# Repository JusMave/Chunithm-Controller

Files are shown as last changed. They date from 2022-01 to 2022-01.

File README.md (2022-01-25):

# Chunithm-Controller
This is a customed controller for SAGA's arcade game "Chunithm".

Game Official Link: https://chunithm.sega.com/

My Controller Demo Video: https://www.bilibili.com/video/BV13k4y1k7Bm

### Introduction
  Chunithm is a classical rhythm game with two types of inputs. 
  Users need to touch the screen and raise their hands at the right time to pass the game. 
  The official machine uses a 32-channel touch screen and 8 pairs of infrared detectors to track users' actions.

### Hardware
  My controller also implemented a capacitive touch screen and 8 pairs of infrared detectors to perform the same function.
  The main control chip is ATmega32U4, a powerful and popular chip for individual embedded development.
  It was connected to four capacitance sensor chips. Each of them can accept 4 channels' signals.
  
  In order to save the production cost and make manufacturing more manageable, I also designed PCBs and outer shells. 
  The CAD files are included in "PCB" and "CAD Blueprints"
  
### Software
  This project utilizes the I/O control library provided by Arduino and an open-source program to process serial communication between the control board and game.
  
### Details
  The detailed information is included in "Report.pdf".

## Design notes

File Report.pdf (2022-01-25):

### MACAU UNIVERSITY OF SCIENCE AND TECHNOLOGY

### Faculty of Information Technology

### Thesis for Degree of Bachelor of Science

### Title: “MaveCon” Customizable Universal Arcade Controller

Student Name | : CHEN HANDONG
Student No. | : 1609853Z-I011-0050
Supervisor | : Dai Hong Ning

### May, 2020

# 澳門科技大學

## 資訊科技學院

## 理學學士學位畢業論文

## 論文題目: “MaveCon”客制化泛用型街機控制器

姓 名 | : 陳漢棟
學 號 | : 1609853Z-I011-0050

## 指導老師 : 戴弘寧

2020 年 5 月

I

## Abstract

The golden age of arcade video games has already ended but there still are a

couple of players spend their times and money in game centers to enjoy the fun which

consoles can’t give them. However, because of the high price of arcade cabinet and low

level of population of this kind of games not every game center will buy the latest or the

most high-quality arcade games. Therefore, not everyone in the world have the chance

to play the game they want. Besides, even somebody is lucky enough. They will still

suffer from long travel distance, expensive gaming cost, long time for waiting in line

and terrible maintenance of arcade cabinet.

In order to solve these problems and help more people be able to enjoy this

fascinating but hard-core game category, we present MAVECON, a customizable

universal arcade controller which can let people play any arcade games in their home.

Because almost every arcade game has their own unique input devices especially for

Japanese rhythm games, the controller divide input sensors set and main board into two

parts. These two parts can use JST PH2.0 connectors to connect each other. Therefore,

users can easily change their sensors to fit various arcade games and maintain the

controller to keep its good performance.

At present, we have completed two games’s sensors set. They are Chunithm [2]

and Taiko set. These two games both are well-known rhythm arcade games in Japan and

have a large player base in the world. Chunithm sensors set includes a PMMA

controller shell, 6 pairs Active Infrared Sensors, 32 capacitive touch sensors and 96

TM1812 RGB programable LEDs. Taiko sensors set includes a dedicated wooden shell

and four shock sensors. What’s more, with long time testing, we can be sure to say that

our controller can give almost the same game experience just like real arcade cabinet.

Keywords: home controller; arcade games; universal; customizable

II

摘要

### 雖然街機遊戲的黃金時代已經結束了，但是如今依然有一部分玩家每天在

### 遊戲廳內遊玩街機遊戲來獲得主機遊戲所給予不了的快樂。然而因為街機框體的

### 高價和玩家人數的稀少，並不是所有遊戲廳都會購入最新或者品質最好的街機遊

### 戲。因此並不是所有人都能有機會玩到自己想玩的遊戲。即便遊戲廳有對應的街

### 機，玩家依然要面臨大量的通勤時間，高昂的遊玩價格，極長的排隊等待時間以

### 及街機框體糟糕的維護等嚴重影響遊戲體驗的問題。

### 為了解決這些問題，我們提出了 MAVECON 一款客制化泛用型街機控制

### 器，它可以讓玩家在家中玩到任何想玩的街機遊戲。我們將控制器分為輸入感測

### 器和主控板兩個部分，來應對幾乎每一款街機遊戲都有他們自己獨特的輸入裝置

### 和對應的輸入方式的問題。他們之間可以使用 JST PH2.0 標準插頭連接。玩家可

### 以輕鬆的更換感測器套組來適應不同遊戲的需求並維護設備保持較好的性能。

### 目前我們完成 Chunithm 以及太鼓達人的感測器套組。他們都是在日本十

### 分有名的街機音遊，即便是在如今的環境下在全球範圍內都依然擁有龐大的玩家

### 基數。Chunithm 套組中包含了一個控制器框體，6 對紅外對射感測器，32 個電

### 容觸摸按鍵， 96 顆 TM1812 RGB 可程式設計 LED。太鼓套組包含一套對應框

### 體以及 4 顆震動感測器。經過長時間的測試，我們已經確定該控制器可以給予玩

### 家與真實街機框體幾乎一致的遊戲體驗。

## 關鍵詞﹕遊戲控制器 ﹔ 街機遊戲 ﹔泛用型﹔客制化

III

## Table of Contents

Abstract | I
摘要 | II
Table of Contents | III
List of Figures | VI
List of Tables | VII

IV

V

VI

## List of Figures

VII

## List of Tables

Chapter 1 Introduction

## Chapter 1 Introduction

## 1.1 Background and motivation

Arcade games [1] are one of the oldest and most special game categories across

the history of video games. They are known by their dedicated and highly immersion

game control approaches, superior difficulty and unbelievable complex game

mechanisms which means arcade games cannot be passed without several years

practice. These features made arcade games become the most popular game category

between the late 1970s and the mid-1980s and this period is defined the golden age of

arcade video games.[1] However, with time going by, these features also become the

biggest blocks for attracting new players to this game category. Because of the superior

difficulty and complex game mechanism, people usually need to play it a couple of

years to be a good player which can be costly for both time and money. What’s more,

arcade game devices are extremely expensive and difficult to transport. Therefore, there

are few game centers have the latest and most high-quality arcade games.

Unfortunately, game centers are the only place for more than 99% people to play arcade

games. Hence, the number of arcade game players are going down year by year.

However, in the Japanese gaming industry, arcades have remained popular

through to the present day.[1] There are still many game companies developing new

arcade machines and games. They are still trying to bring some creative features to

improve gameplay. As of 2009, out of Japan's US$20 billion gaming market, US$6

billion of that amount is generated from arcades, which represent the largest sector of

the Japanese video game market, followed by home console games and mobile games at

US$3.5 billion and US$2 billion, respectively.[4] Hence, there are still a couple of

arcade players and people who want to be arcade player in the world. To better help

these people enjoy arcade games, we need to know what make this kind of game is so

hard for players to play.

Generally, problems for people to play arcade games can be divided into two

types. One kind of problems are about cost of playing arcade games including the time

spending on traveling and waiting, the money spending in starting each round. Another

kind of problems are about the rarity of arcade cabinets which means people are hard to

Chapter 1 Introduction

find the arcade game which they want to play. For example, there are total 420 game

centers and 1293 arcade rhythm game machines in China.[5] Most of them are in first-

tier cities. Hence, only few people in China have the chance to play the latest arcade

rhythm games.

In order to solve these two kinds of problems and encourage people to play arcade

games, we developed a fully customizable arcade game home controller which we

called MaveCon. It can be connected to PC, PS4, Nintendo Switch and any other

platforms. It can be used to simulate any arcade games including fighting games,

rhythm games, shooting games and even simulation games in arcade platform. To

achieve these goals, we divide the controller into two parts. One is sensor set which

including all the sensors which you need to simulate the input of arcade cabinet and a

strong shell to fix all the sensors to ensure all the sensors can work properly when users

are playing. Another one is the main control board which are used to control all the

sensors and convert input signals from sensors to output signals which can be

recognized by target platform. At present, there are some different types of arcade game

home controllers in the market. However, because of the unique input approach of each

arcade game. Most controllers can only be used to play one game. What’s more, these

controllers usually are very expensive and cannot be customized. Therefore, those

controllers cannot fulfill everyone’s needs.

All in all, the main goal of us is developing a controller which can give everybody

a chance to play those interesting but rare arcade games without cost lots of money. In

other words, we want to design and implement a controller with low price, high

performance and high productivity. The original design of the controller is for arcade

rhythm games. There is no doubt that the controller can be used in any arcade games.

However, currently we have only finished Chunithm and Taiko sensors set and we

spend most of our effort on Chunithm sensors set. Therefore, we will use Chunithm set

as the sensors set example in this thesis.

## 1.2 Contributions

We present a functional action detecting system including a budget but powerful

self-capacitance touch pad and several high accuracy hands’ position tracking sensors.

Chapter 1 Introduction

We present a cross platform sensor data converting system including a main

board with modular and customizable input interfaces, a high-performance sensors

signals processing approach, HID device simulation function and cross platform feature.

## 1.3 Thesis organization

Chapter 2, we introduce the architecture of MAVECON.

Chapter 3, the details of hardware development in this chapter.

Chapter 4, we describe the implementation of our controller’s software.

Chapter 5, testing and evaluation will be discussed in this chapter.

Chapter 6 concludes the thesis.

Chapter 2 Architecture

## Chapter 2 Architecture

In this chapter, we will illustrate the architecture of MAVECON, which can give

a better understanding of the controller.

## 2.1 Overview

MAVECON consists of three parts. They are sensors set, main board and the code

burned inside the chip. The detailed structure of each part as shown in figure 2-1. Each

part has its unique and irreplaceable functions which will be illustrated in next sections.

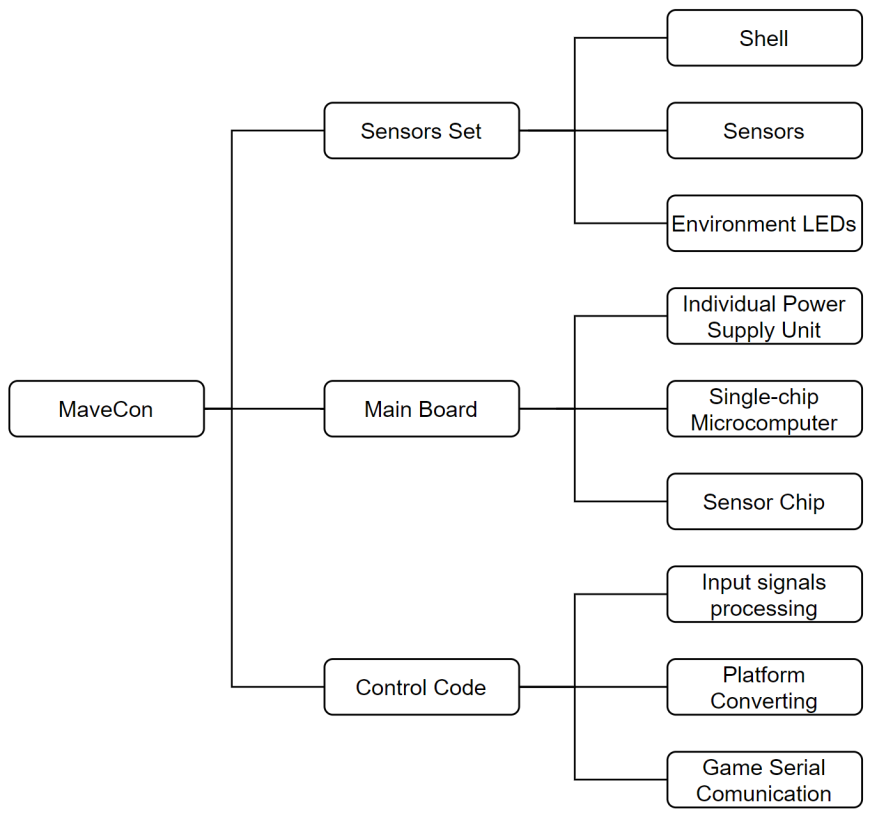
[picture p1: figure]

Figure 2.1 Controller Overview

## 2.2 Sensors Set

Sensors set has three parts including outer shell, sensors and environment LEDs

which is the most significant part for controller to be able to simulate various

completely different arcade games. Users can play different games by changing their

sensors set. All the sets will be budget and easy for users to use. Currently, we have

Chapter 2 Architecture

designed and implemented Chunithm sensors set. We can produce more sets and

improve their performance in the future.

2.2.1 Shell

Shell is used to fix all the sensors and ensure they can work properly when user is

playing. Arcade games are not like those games in consoles or PC. Players are using

individual input devices like controller, keyboard and mouse to give commands and

signals to play the game. Arcade games combine the input devices, screen and any other

devices together in a shell which is called cabinet. What’s more, because of the playing

place of arcade games and hard game difficulty, the cabinet usually cannot get high-

quality maintenance and will be hit hard by players to release their angry and regret.

Hence, almost all the arcade cabinet will be protected very will using industry level

impact resistance materials. The situation is similar for home arcade controller. Because

of the arcade game mechanism especially for rhythm games, players have to hit sensors

very hard to keep their sense of rhythm the same as the game to get a high score.

Therefore, the controller should use strong shell to fix all the sensors and protect them.

Generally, we will use PMMA¹
and 304 stainless steel which both are good

material for making the shell. PMMA is a kind of material with good impact strength

and the most important thing is its low price. For our Chunithm sensors set, we use

PMMA to make the entire shell base and other individual shell parts.

2.2.2 Sensors

Sensors is the most important part of sensors set. They are used to simulate the

same kind of input signals as the arcade games. For example, the main input devices of

Chunithm are one touch screen with 32 touch areas and 6 pairs of air sensors. Hence, in

order to simulate these two kinds of input signals, we use 32 capacitive touch sensors to

input touch, hold and slide signals and 6 pairs Active Infrared Sensors to give air

signals. In order to make all the sensors work in a terrible environment and meet our

1 PMMA: Poly (methyl methacrylate), https://en.wikipedia.org/wiki/Poly(methyl_methacrylate).

Chapter 2 Architecture

original intention of developing such a controller, sensors should be highly reliable and

budget. Hence, we will only choose the most common sensors to make our sensors set.

2.2.3 Environment LEDs

Almost all the arcade video games have complex lighting system which can be

used to show the feedback of user input signals or help games improve the gameplay.

For the controller, environment LEDs have the same function just like arcade games. To

achieve this goal, we choose RGB LEDs with IC chip which can be controlled by address like WS2812B and TM1812²
. Hence, these LEDs can show complex light

effect or even do the same like real arcade games. Most arcade games use serial

communication to control LEDs. What’s more, we have already programed a simple

serial communication port to using arcade games original light system control logical.

Therefore, with correct led settings the controller can have the same light effect just like

real arcade games’ cabinet.

## 2.3 Main Board

The main board of our controller is consisted by single-chip microcomputer,

sensor chip and individual power supply unit. The major function of it is handling input

signals from sensors and output these signals to the arcade games working on different

platforms and provide strong power to support various devices in the controller. To

make the controller easy for users to use, we use JST PH2.0 [16] standard connectors to

connect main board and sensors.

2.3.1 Single-chip Microcomputer

Single-chip microcomputer is the major part in the main board. All the logical

control codes are burned in it including input signals handling, platform converting and

LEDs serial communication. To develop such a hardware-based controller, using single-

chip microcomputer is the best option. Because with the help of suitable single-chip

microcomputer, developers can use high level program languages and take benefit from

2 WS2812B and TM1812 both are an Intelligent control LED integrated light source which can be controlled

by IC chip and output RGB lights. WS2812B’s light direction is vertical to PCB board and TM1812’s light direction

is parallel to the PCB board.

Chapter 2 Architecture

the community. At present, there are countless suitable single-chip microcomputer in

the market. Different microchips have different pros and cons. In this thesis, we use

Arduino pro micro to be our single-chip microcomputer. Because Arduino pro micro

has the best performance and smallest volume among all the supported Arduino compatible boards of keyboard HID library. Sparkfun pro micro uses ATmega32U4³

chip which has powerful performance for making a home gaming controller. What’s

more, pro micro is the smallest Arduino boards among all the products of Arduino.

Hence, the main control board can be small but powerful to reduce the need of setting

space and keep users’ great game experience. Besides, Atmega32U4 is one of the most

common chips in embedded development. Therefore, we can use countless useful third-

party libraries to reduce the cost of our development and improve the performance of

our controller.

2.3.2 Sensor Chip

Sensor chips are necessary part for handling complex sensors like capacitive

touch sensors. Because these sensors do not produce simple digital signals, developers

have to use a complex algorithm to calculate the output value from the sensors and

convert them into simple digital signals. To reduce the effort of making such a

complicated algorithm and its hardware circuit, we use dedicated sensor chips to

complete the job. We use MPR121 to be our sensor chip which are design for capacitive

touch sensors, but it also can handle those sensors which can produce digital signals by

themselves like microswitches. What’s more, multiple MPR121 chips can be called by

their addresses. Hence, we can use multiple sensor chips to manage different groups of

sensors. Because of that, we can greatly increase the range of arcade games which can

be simulated by our controller and reduce the difficulty of maintenance. Besides,

MPR121 has a complex but fully customizable debounce algorithm, a simple static

3 ATmega32U4 is a low-power Microchip 8-bit AVR RISC-based microcontroller featuring 32KB self-

programming flash program memory, 2.5KB SRAM, 1KB EEPROM, USB 2.0 full-speed/low speed device, 12-

channel 10-bit A/D-converter, and JTAG interface for on-chip-debug. The device achieves up to 16 MIPS throughput

at 16 MHz, 2.7 - 5.5 Volt operation.

Chapter 2 Architecture

threshold setting and a dynamic baseline system which can improve the performance of

capacitive touch sensors and make our controller be more customizable.

2.3.3 Individual Power Supply Unit

The function of individual power supply unit is providing enough power to

support all the devices in the controller. The original USB port can only provide 800ma

power which is enough for the microcomputer and sensor chips, but it’s not enough for

LEDs and other high cost devices. Without enough power the reliability of each part in

controller will be greatly reduced. Some sensors and chips may shut down and

microcomputer will also have some running problems. Hence, we use an individual

power supply unit to support the costliest devices in the system. The whole Chunithm

sensors set has 96 LEDs. Each of them needs 60ma power. Hence, if all the LEDs

working full loaded the total power input should be more than 5.76A. Fortunately, full

loaded situation is very rare. Therefore, we use a 5A/24V DC power unit which can

output a little bit less power than the full loaded situation to support the controller. It

can fulfill our needs and make main board power supply traces be smaller to remain

more spaces for logical traces.

## 2.4 Control Code

Control code is burned in the main single-chip microcomputer. The main function

for control code is receiving input signals from sensors and output specific signals to

communicate with different platform using serial or USB communication protocol.

2.4.1 Input signals processing

Most sensors will provide simple digital signals, some other sensors need

algorithms to convert their output value into digital code. All of these signals will be

handled by input signals handler. Handler will use signals to do communication with

arcade games and users can use controller to play the game with the same gameplay as

real arcade cabinet. To improve the performance of sensors, we implemented an

effective debounce algorithm. The technical details will be presented in software

chapter.

Chapter 2 Architecture

2.4.2 Platform Converting

There are a couple of arcade games released console or PC versions. That means

some players may not only want to play arcade games running in PC simulators, but

also want to play those console versions. Hence, we implemented a platform converting

feature. Currently, it can support PS4 and Nintendo Switch. By changing the HID

document, Atmega32U4 can simulate different kinds of input devices like keyboard,

mouse and gaming controller. Currently, only PC and Nintendo Switch can be

simulated by Arduino HID library. For PS4 and other platforms’ simulation, we use

GIMX [6], a well-known free software that allows to use a computer as a hub for

gaming devices. By using our Taiko sensors set, we can play

2.4.3 Game Serial Communication

Most of the arcade games use serial port and serial communication to control

sensors and other I/O devices. If we can use the original serial port to transfer I/O

signals, the input latency will be greatly reduced. Hence, for some games which have

been decrypted and known their serial communication structure, we will use their serial

port to transfer signals especially environment LEDs.

Chapter 3 Development of Hardware

## Chapter 3 Development of Hardware

In this chapter, we will illustrate the technical details of hardware implementation

of our controller and Chunithm sensors set. To improve the performance and reduce the

difficulty of future maintenance, we use modularized structure and development

method. The basic running routine for hardware as shown in Figure 3-1.

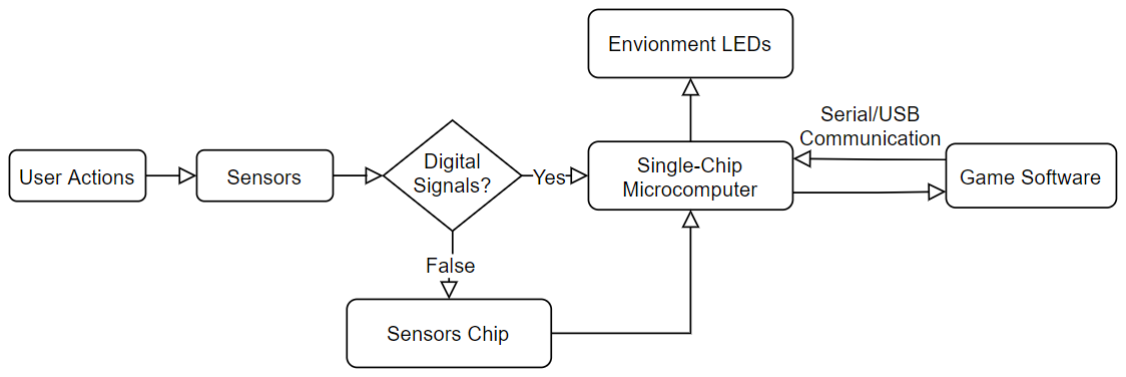
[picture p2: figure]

Figure 3.1 Data Flow of the System

## 3.1 User actions detecting by Sensors

To provider users the same gameplay as the real arcade games, designing a

suitable approach for users to input commands by doing the same actions as real arcade

machine is essential. For Chunithm sensors set, we designed an approach to track users’

input commands just like Chunithm arcade machine.

3.1.1 Game Mechanism

In order to give better understanding for why we designed such an approach, it is

necessary to know the game basic mechanisms.

Chunithm is a modern drop-style rhythm game in arcade platform. This kind of

games use a scrolling "note highway" to display what notes are to be played, along with

a score and a performance meter. Generally, players need to input click, hold to play the

game. If players can keep inputting right commands at right timing, they can get score.

Otherwise, they cannot get score and will lose their HP. The game will fail when the HP

is 0. There are totally four kinds of actions in Chunithm. They are touch, hold, slide and

Chapter 3 Development of Hardware

air. Players need to touch and release the touch screen immediately to generate touch

signal. Keeping touching the screen will give hold signals. If players keep touching the

screen and slide their hands from one area to another area, it will provide slide signals.

Finally, air signals will be generated when players hover in the air and between air

sensors.

3.1.2 Selection of Sensors

To generate touch, hold and slide signals and try to simulate the gameplay as

better as possible. We decide to use touch screen to complete the job. Arcade machine

uses acoustic wave type touch screen which is an extremely rare and expensive

approach. To keep our controller budget for everyone can get, we decide to use other

more common approaches to implement touch screen. There are two common touch

screen implementation methods in the world. First is capacitive touch screen, second is

resistive touch screen. The former one has the advantages of lower prices and more

simple structure which can be made even without professional industry machines.

Besides, it is more suitable to make such a big touch screen without precise position

detecting. Hence, we decide to use capacitive touch screen to be our main input sensors.

To output air signals, we need to detect the position of users’ hands. Only output

air signals, when users’ hands hovering at a specific height. There are two effective

approaches. First, we can use a camera and a motion detecting algorithm to track the

position of hands. Second, using sensors to directly detect whether there are hands

going through. First approach needs much bigger space than the second one. Because

we need enough distance to make camera work properly. Besides, if we use first

approach, the whole system will be much more unreliable. The devices settings will be

insignificantly difficult to calibrate. Hence, we decide to use Active Infrared Sensors to

finish the job. Those sensors have excellent performance for tracking objects’ position.

They can output digital signals with an extraordinary low latency which can be a major

benefit for a rhythm gaming controller.

Chapter 3 Development of Hardware

3.1.3 Implementation of Sensors

### 3.1.3.1 Capacitive Touch Screen

Capacitive touch screen uses capacitive sensing technology, based on capacitive

coupling, that can detect and measure anything that is conductive or has a dielectric

different from air. Its technical principles as shown in Figure 3-2

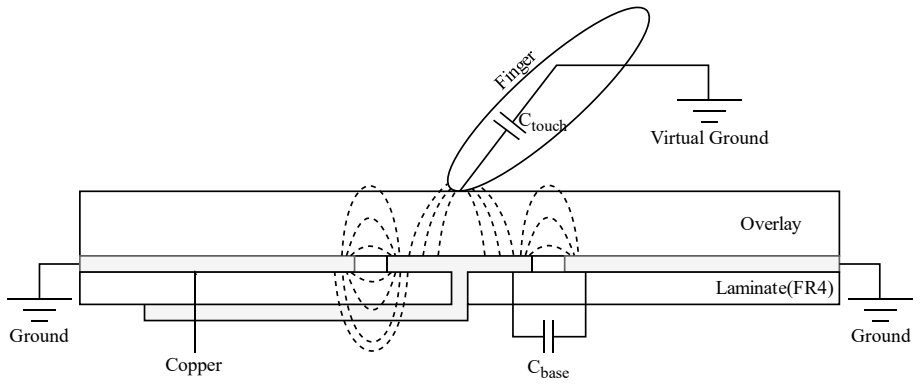
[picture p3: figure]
Cbase; Ground; irtual Ground; Ctouch; Laminate FR4; Overlay; Copper

Figure 3.2 Capacitive Sensor Overview

A capacitor is a device that stores electrical energy in an electric field. It is a

passive electronic component with two terminals. For capacitive touch screen, copper

and finger are the two terminals and overlay are dielectric medium. Hence, we can get a

capacitor and detecting the touch action by tracking the change of electrical energy in

this capacitor.

According to the basic theory of parallel-plate capacitor, we can get the formula.

The capacitance is defined as C = Q/V. Hence, here is the final formula for

capacitive sensors.

Therefore, in a capacitor the highest capacitance is achieved with a high dielectric

constant material, large plate area, and small separation between the plates. What’s

Chapter 3 Development of Hardware

more, the highest capacitance means the sensitive of the sensor. Higher sensitive can

give clearer and stronger signals. Therefore, in order to get as higher sensitive as we

can, we increased the size of copper terminal, thinner and higher permittivity dielectric

overlay. There are a couple of approaches to implement a functional capacitive touch

sensor. We can use ITO, metal, PCB board and many other materials to complete it. In

order to reduce the difficulty of manufacture and assembly. We decide to use PCB to

make our capacitive touch sensor. Besides, environment LEDs will also be soldered on

the touch sensor board. To find the best sensor PCB, we designed and tested three versions of PCB design. The first version PCB design⁴
of capacitive touch sensor as

shown in Figure 3-3.

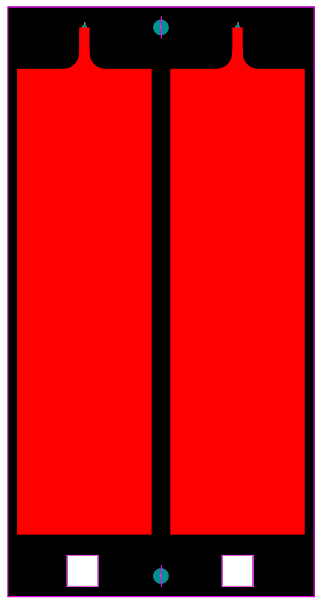
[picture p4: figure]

Figure 3.3 Capacitive Sensor Board V1.0

4 We use Altium Designer 2020 and AutoCAD 2020 to draw all the parts. All the color and meaning of line

and icons will follow their default settings. All the PCB board in this thesis follow the standard:

⚫ | 1.6mm.FR2
⚫ | Solder mask over bare copper
⚫ | 1oz copper
⚫ | Solder mask on both layers
⚫ | Supplied as singles

Chapter 3 Development of Hardware

We will use 8 sensor boards to form touch screen. It has totally 16 touch areas

and 16 WS2812B environment LEDs. The overlay uses PMMA material with frosted

surface which have high permittivity dielectric and can help lights have a better effect.

However, the V1.0 design has three problems.

⚫ | The sensors cannot detect touching if users touch the area between two
| copper areas.
⚫ | Because of the uneven surface of frosted PMMA material, there is air
| between copper and overlay. Hence, the sensitivity of sensors is influenced. It
| will be a little bit lower than normal PMMA surface.
⚫ | The game software needs 32 touch areas, but by using V1.0 design we can
| only support 16 touch areas. Therefore, we designed another version to fix
| these problems.

Hence, we designed another version of our sensor board and overlay. The second

version of capacitive touch sensor as shown in Figure 3-4.

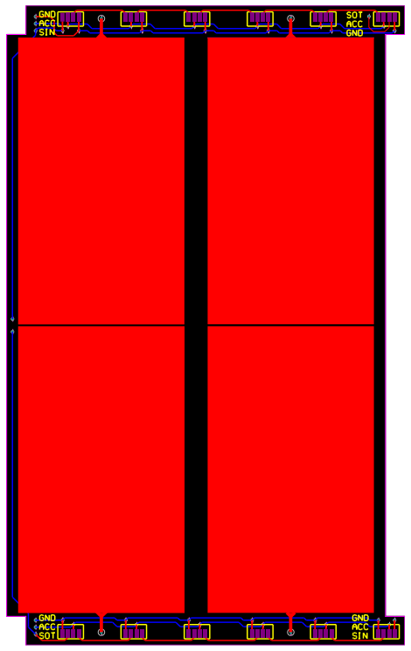
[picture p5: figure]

Figure 3.4 Capacitive Sensor Board V2.0

Chapter 3 Development of Hardware

In the sensor board V2.0, we divide one touch area into two areas to support 32

touch areas like arcade machine. Besides, we added environment LEDs’ soldering area

to combine the LEDs and sensors board together to improve the performance of lighting

system and simplify assemble process. The material of overlay is also changed. We

select laser dotted light guide plate (LGP) which are made by PMMA material with

smooth surface. Hence, there is less air between copper and overlay than frosted surface

PMMA which can improve the sensitivity of sensors. The technical details about laser

dotted LGP will be illustrated in next sub section.

After testing the second version sensor board, we conclude all the benefits from

each version design and present our final version sensor board as shown in Figure 3-5.

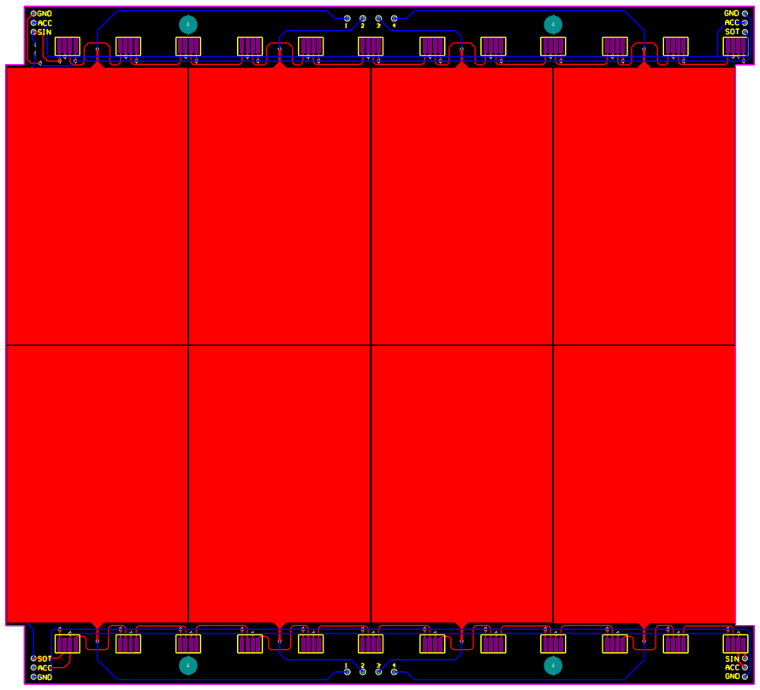
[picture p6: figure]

Figure 3.5 Capacitive Sensor Board Final Version

### 3.1.3.2 Active Infrared Sensors

Active infrared sensors usually consist of a pair of electronic sensors that

measures infrared (IR) light. One is the transmitting end and another is the receiving

end. Transmitting end will continuously beam IR light. If the IR light is blocked by

Chapter 3 Development of Hardware

some objects, the receiving end cannot receive the IR light. Then, it will generate digital

signals and send them through the signal port. Because of the physical features of IR

light and the special structure of the devices, IR light can travel long distance with high

strength.

There are two types of Active infrared sensors. Break beam sensors and

reflectance sensors.

Break beam sensors have emitter and receiver placed face to face that the IR

emitted by the emitter falls directly in to the receiver. During the operation, IR beam is

emitted continuously towards the receiver. The flow of IR can be interrupted by placing

an object between the emitter and receiver. If the IR is transmitted but altered then

receiver generates output based on the change in radiation. Similarly, if the radiation is

completely blocked the receiver can detect it and provide the desired output. For

example: let’s consider a Break beam sensor and a conveyer belt as shown in figure 3-6.

When an opaque object interrupts the IR flow the receiver doesn’t receive any signal

thus the conveyer belt stops.[8]

Figure 3.6 Break Beam Sensor

Reflectance sensors use reflective property of IR. The emitter emits an IR beam

which is reflected by the object. The reflected IR is the detected by the receiver. The

object causes change in the property of the reflected IR or the amount of IR received by

the receiver varies. The degree of change is dependent on the reflectance of the object.

Thus, detecting the change in amount of received IR helps in figuring out the properties

of object such as surface geography and reflectance.[8]

Chapter 3 Development of Hardware

Figure 3.7 Reflectance Sensor

Because of the game mechanism, break beam sensor is more suitable for our

controller. Besides, it can be easier to calibrate and generate clear digital signals. Hence,

we use a shell structure to fix six pairs of break beam sensors to track users’ action.

Because game software only supports six signal inputs, so we only use six pairs of

sensors.

In order to improve their performance in different working environment

especially working with other light source which may interfere the function of receiving

end, we select active IR sensors using modulated light signals. That means the emitter

will emit light in a special frequency and the receiving end will only generate signals

when it cannot receive the light in that frequency.

Figure 3.8 Modulated Active IR Sensors

However, when we use multiple active IR sensors together, there are another

problem. The receiver may receiver light signals from other IR emitters, which means it

will not generator signals even there is an object between it and its original IR emitter.

Chapter 3 Development of Hardware

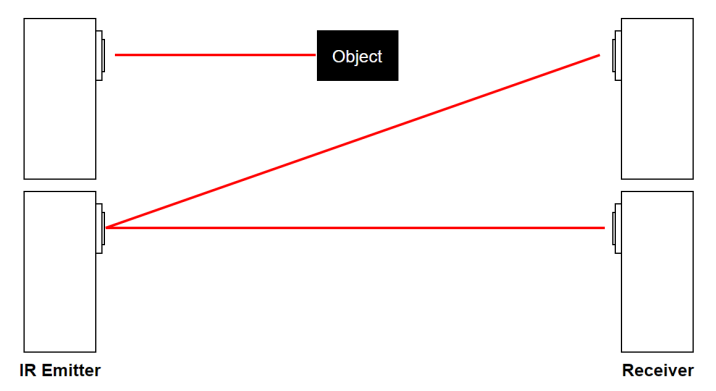
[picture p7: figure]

Figure 3.9 Receiving Light from Other Emitter

So, we designed a cover panel to block light signals from other IR emitters. This

panel can also greatly improve the sensor performance in bright environment.

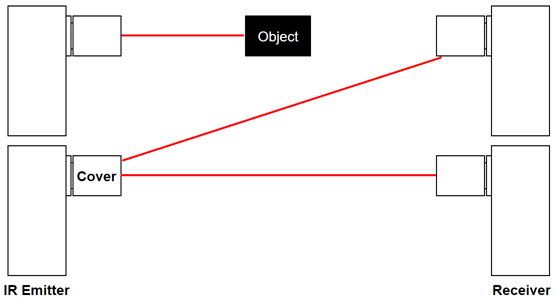
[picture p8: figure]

Figure 3.10 Extra Cover Panel

## 3.2 Design and Implementation of Shell and LEDs

3.2.1 Outer Shell

In order to fix all the sensors and give more customization possibility, we spend a

lot of effort to design a suitable shell for our controller. Because of the demand of

different sensors, outer shell has two parts to install different types of sensor which are

shell base, top panel and air sensor holder.

### 3.2.1.1 Shell Base

Shell base is the most significant part for keeping the controller stable when users

are playing. To increase its strength, we first tried 304 stainless steel, which is a

common metal material in industry products. The design is shown in Figure 3-11.

Chapter 3 Development of Hardware

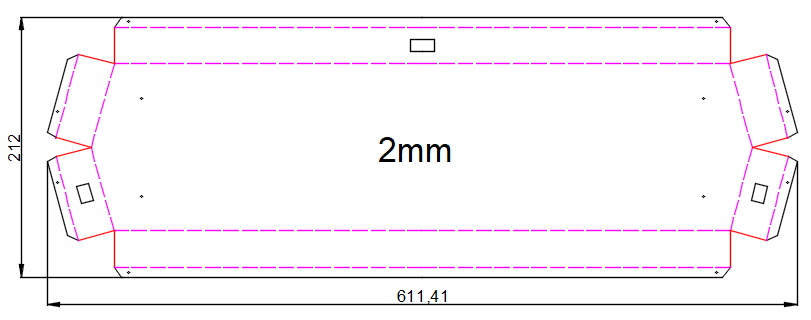
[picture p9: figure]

Figure 3.11 Steel Shell Base V1.0⁵

However, the error of steel material bending and welding process is too serious to

pass our assembly test. Therefore, we decide to use PMMA material to build outer shell

and try to design each part as simpler as possible to reduce process difficulty. The

design is shown in Figure 3-12.

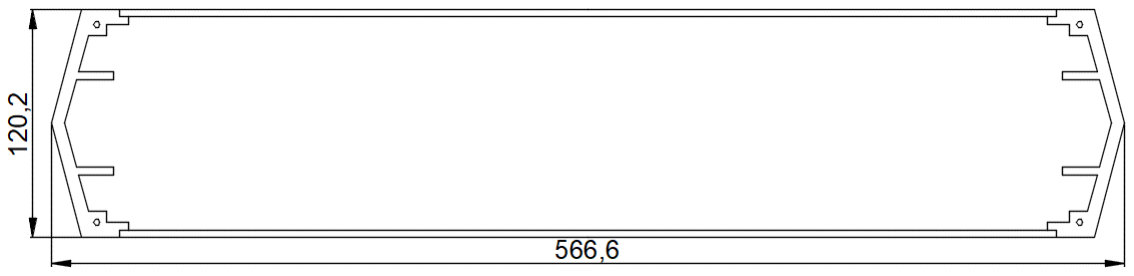
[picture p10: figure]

Figure 3.12 PMMA Shell Base V2.0

### 3.2.1.2 Top panel

Top panel are used to fix all the touch sensors and connect to air sensor holder.

Besides, it should be removable. Because the controller should be easy for users to

5 Followings are the meanings of all the icon and color in CAD Drawings:

Black Line: Cutting line

Red Line: Welding line

Pink Line: Bending line

The unit of all the number: mm

Chapter 3 Development of Hardware

maintenance. Hence, each part in the controller having possibility to be broken should

be replaceable without special tools. The design is shown om Figure 3-13.

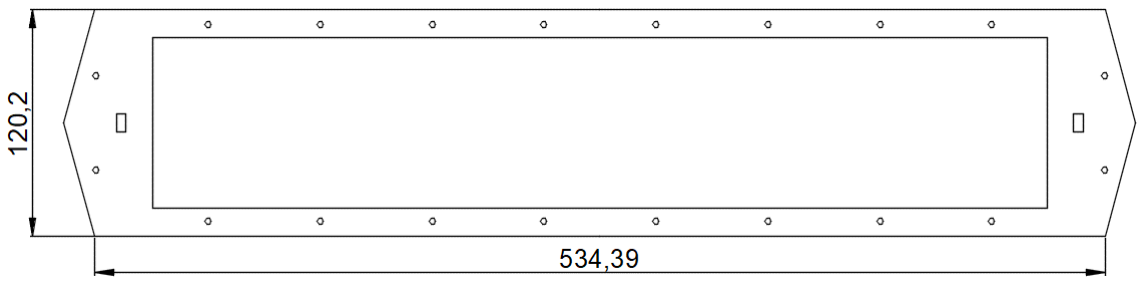
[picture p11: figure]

Figure 3.13 PMMA Top Panel

### 3.2.1.3 Air Sensor Holder

air sensor holder is the part have the most components. It is used to install active

IR sensors. Because the detecting area of IR sensors are not big enough. Hence, we

create customizable sensor base to make the controller can fit anyone’s demand. Users

can choose to stand and play the controller like playing arcade machines or sit on the

chair and play games like playing console games. Because of the basic technical

principle of active IR sensors, they need a dark environment to perform their function.

Hence, we added extra cover panels which can be installed on the holder to keep sensors

working in a dark environment. Whether to install these panels and install how many

panels depend on users. Our design can support cover panels up to 4. All the

components are shown in Figure 3-14.

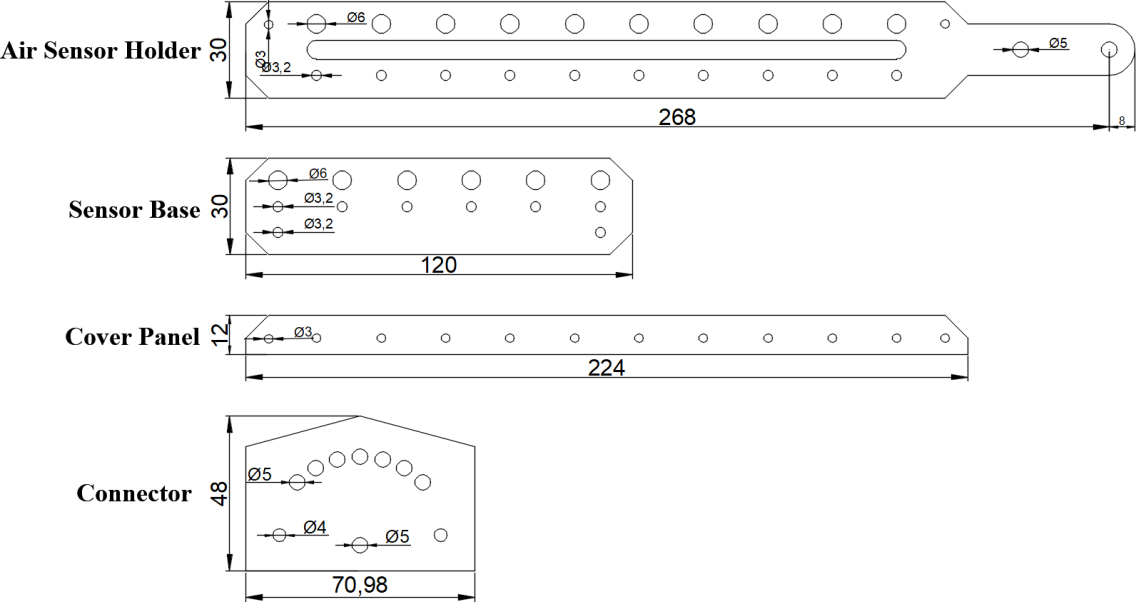
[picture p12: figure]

Figure 3.14 The CAD Drawing of Air Sensor Holder V1.0

Chapter 3 Development of Hardware

3.2.2 Environment LED

Environment light system is made by two parts. The LED and LGP. The first

version of LGP frame design as shown in Figure 3-15.

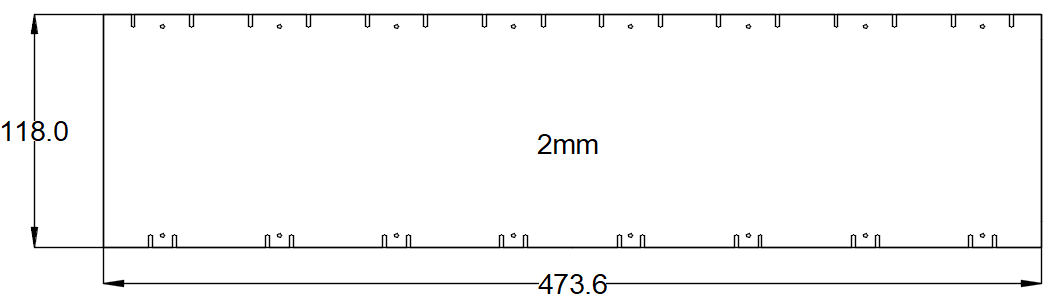
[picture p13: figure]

Figure 3.15 LGP Frame V1.0 CAD Drawing

We use this version of LGP frame with WS2812B LED [9] as shown in Figure 3-

16.

Figure 3.16 WS2812B

WS2812B is an intelligent control LED light source that the control circuit and

RGB chip are integrated in a package of 5050 components.[9] It is a very popular and

useful RGB LED in industry scale. Thousands of programable lighting systems are

made by WS2812B. Hence, in the first version design, we also tried this kind of LED.

However, common WS2812B using the 5050 packages. Hence, they can only

emit light to vertical direction. After physical test, the effect of this approach is not

good. They can only light up a small area of LGP. Besides, the first version of LGP

frame design also has problems about different LEDs’ light may interfering each other

which means the light effect are not clear enough for players to recognize their input

commands by watching the light color. Therefore, in order to construct a high-quality

lighting system. We redesigned back light unit structure. The new structure as shown in

Figure 3-17.

Chapter 3 Development of Hardware

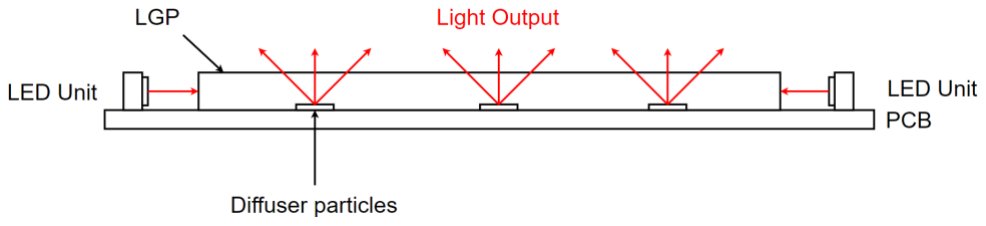
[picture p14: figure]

Figure 3.17 Back Light Unit (Backlit unit) Structure

This back light unit structure needs a LED can emit light in parallel direction and

a suitable LGP frame design. Firstly, we select a TM1812 [10] RGB LED. It has similar

appearance and functions to WS2812B, but it uses a different package to emit parallel

light. Secondly, we designed the second version of LGP frame which can use reflective

coating to prevent light interfering. The design is shown in Figure 3-18.

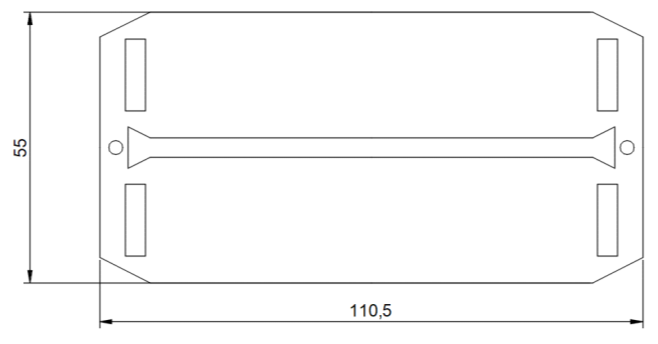
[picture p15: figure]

Figure 3.18 LGP Frame V2.0 CAD Drawing

Besides, we also need to select a suitable type of light guide plate (LGP) to be the

LGP frame material. Generally, there are two types of LGP in industry scale. They are

laser LGP and silk print LGP. The differences are shown in table 3-1.

Type of LGP | Reflector Method | Dimensions | Reflecting Material | Anti-UV | Light Transmittance Rate | Error | Quality Guarantee | Application Environment
Laser Dotted | Laser Concaved Point | 3D | No Addition Material | Yes | 93% | 0.1mm | 10 years | Indoor and outdoor
Sile Print | Raised Point | 2D | Print Ink | No | 70% | 1mm | 2 years | Indoor only

Table 3.1 Comparison between the Laser LGP and Silk print LGP

Chapter 3 Development of Hardware

Hence, we can find that laser dotted LGP has much more advantages than silk

print LGP. What’s more, the material of laser dotted LGP is Mitsubishi optical acrylic

(PMMA) which has many excellent features including high light transmittance,

uniformity reach to 90%, no yellowing, long life span (at least 10 years), no addition

chemical substance and high permittivity dielectric. Because of these advantages, we

select it to be the material to make our LGP frame. [11]

## 3.3 Implementation of Main Board

In this section, we will illustrate the approach to implement main board. It is

consisted by four sensor chips and one single-chip microcomputer. Main board is used

to process all the input signals and output processed signals to game platform.

3.3.1 Sensor chips

Because not all the sensors can generate simple digital signals by themselves.

Some sensors can only output analog signals or other types of value. Hence, we need

use special algorithm to handle these output values and convert them into direct and

effect value to track users’ action. In order to reduce the cost of development and

enhance the reliability of our system, we use Adafruit MPR121 12-channel capacitive

touch sensor breakout board’s compatible board to finish the job. MPR121 can handle

up to 12 individual touch pads. The MPR121 has support for only I2C, which can be

implemented with nearly any microcontroller. Developers can select one of 4 addresses

with the ADDR pin, for a total of 48 capacitive touch pads on one I2C 2-wire bus.

Using this chip is a lot easier than doing the capacitive sensing with analog inputs: it

handles all the filtering for users and can be configured for more/less sensitivity. [12]

Because of these features, we can use MPR121 to implement a touch screen

including at most 48 touch pads which can be fit most arcade games’ demand. Besides,

the board can process not only analog signals, but also digital signals. Hence, we can

connect sensors which can generate digital signals like microswitches to the board. It

can greatly enhance the generality of our controller. Users also can find some creative

approaches to implement their own controller by using our main board. The MPR121

board is shown in Figure 3-19

Chapter 3 Development of Hardware

Figure 3.19 MPR121- Breakout Compatible Board

3.3.2 Single-chip Microcomputer

There are thousands of various single-chip microcomputers in the market. To give

a better understanding about why we choose Sparkfun pro micro, we will present our

reasons from multiple aspects.

### 3.3.2.1 Requirements of Microcomputer

Before illustrate the reasons, we should know what kind of microcomputer is

suitable for our project.

⚫ | High Performance and High Reliability
⚫ | Big and Active Community
⚫ | Easy for Software and Hardware Development
⚫ | Small Size and Low Price

Firstly, because it is responsible for most computation. If the microcomputer

shutting down or crashed when users are playing, the controller will stop work. Hence,

high performance and high reliability of the microcomputer are very important.

Secondly, because of differences between various microcomputers’ bottom

hardware structure, the implementation of software which have the same functions will

be different. If the microcomputer can be supported well by the community, the

development cost will be greatly decreased. For example, the HID simulation function

is necessary for our project. Popular chips have countless useful and high-quality HID

simulation libraries. By using them, our controller can have a much better performance

Chapter 3 Development of Hardware

and less development time than using most not popular chips. Therefore, we try to find

a most common used microcomputer and have the biggest and most active community.

Thirdly, microcomputer is relative to both software and hardware development.

More exactly, we should use different programing language to develop our software and

design PCB with different complexity to integrate sensor chips and microcomputer

depending on the microcomputer. Hence, we should find a microcomputer which can be

easy for software and hardware development.

Finally, the size of microcomputer should be small with low price. Because our

controller should be able for everyone to play at home. Hence, each component should

be as small as possible except outer shell which should have the same size like arcade

input devices with low price to reduce the cost.

### 3.3.2.2 Selection of Microcomputer

It was estimated in mid-2011 that over 300,000 official Arduinos had been

commercially produced,[5] and in 2013 that 700,000 official boards were in users'

hands. There is no doubt that Arduino products have one of the biggest and most active

community in the world. Hence, we decide to find a suitable product from Arduino

microcomputer product line. The usage of Arduino Board as shown in Figure 3-20.

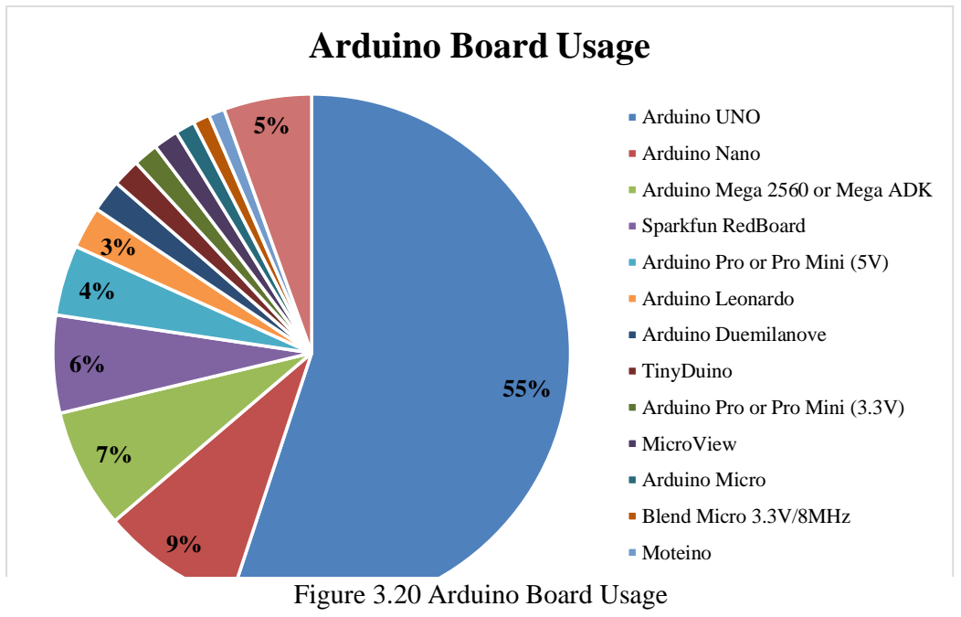
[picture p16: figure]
Arduino Board Usage; Arduino UNO; Arduino Nano; Arduino Mega 2560 or Mega ADK; Sparkfun RedBoard; Arduino Pro or Pro Mini (5V); Arduino Leonardo; Arduino Duemilanove; TinyDuino; Arduino Pro or Pro Mini (3.3V); MicroView; Arduino Micro; Blend Micro 3.3V/8MHz; Moteino Other Figure 3.20 Arduino Board Usage

Chapter 3 Development of Hardware

Arduino UNO definitely is the most common used Arduino Board, but it is too big for

our project. Atmega328P is the most popular processor as shown in Figure 3-21.

However, Atmega32U4 can use the same code running by Atmega328P and it has USB

transceiver inside the chip which can do away with bulky external USB interface.

Hence, we finally decide to use sparkfun pro micro which has a small size, low price

and high performance for us to make a controller. The software development can be

supported by Arduino IDE and many useful third-party libraries.

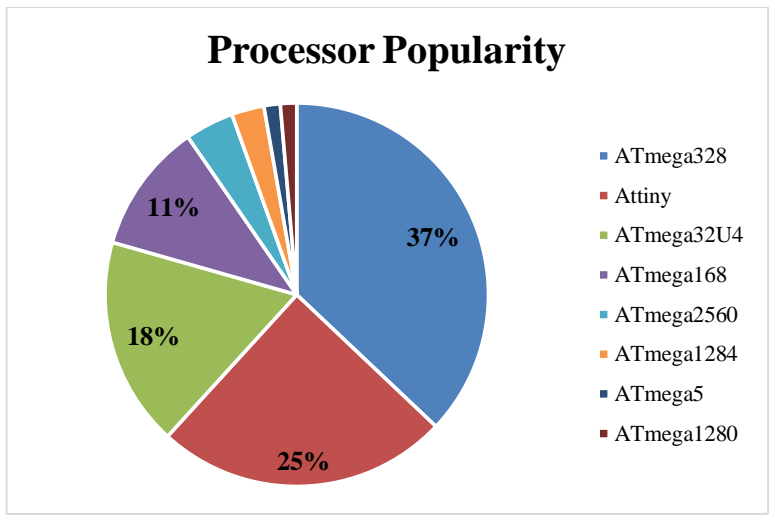
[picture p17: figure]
Processor Popularity; ATmega328; Attiny; ATmega32U4; ATmega168; ATmega2560; ATmega1284; ATmega5; ATmega1280

Figure 3.21 Processor Popularity

Sparkfun Pro Micro has 3.3V and 5V versions. One can run at 3.3V/8MHz.

Another can run at 5V/16MHz. To get higher performance, we select 5V/16MHz

version.

Pro micro can only output 500ma current which is not enough for all the

environment LEDs. Hence, we added an individual power supply unit.

3.3.3 PCB of Main Board

Because of the requirement of our controller, every component in the project

should be fixed well and can be replaced or installed without special tools. Hence, we

designed a PCB to integrate sensor chips, microcomputer and power supply unit. We

Chapter 3 Development of Hardware

also use JST PH2.0 standard connector to reduce the difficulty of connecting sensors to

main board. The design is shown in Figure 3-23.

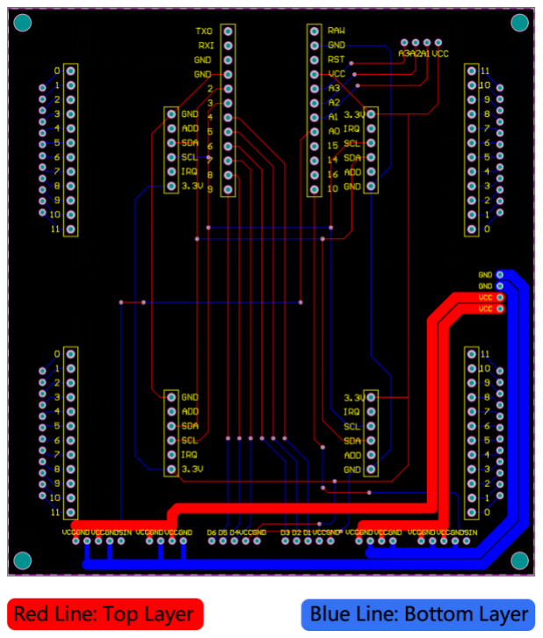
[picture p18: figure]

Figure 3.22 PCB design of Main Board

Environment LEDs need about 5A current. Because of the current heating effect,

we need wider power traces to keep its temperature in the safe zone. The effect is shown

in Figure 3-24. Generally, 5A current needs about 6mm wide trace. However, the space

is not enough for 6mm power traces and ground traces. Therefore, we use 4mm traces

and divide environment LEDs into two group to balance the load of power trace. We try

to design the main board within 10cm * 10cm size is because most PCB producers will

give the lowest price for boards within that size. If the board is larger than 10cm *

10cm, the price will be at least twice the original price. It will greatly increase the

development cost and the difficulty of production.

Chapter 3 Development of Hardware

Figure 3.23 Trace current capacity on 1oz PCB

Besides, we added an extra encoder connector for further development. It can be

used to change current supported game of the controller so that users need not to

recompile or reburn the code to fit different games.

3.3.4 Individual Power Supply Unit

There are various individual power supply units (PSU)in the market. Generally, A

power supply unit is used to convert mains AC to low-voltage regulated DC power for

the internal components of a computer. The function is a little bit different for our

controller. It has an individual AC-DC converter which is used to convert 220V AC

power to 24V DC power. Then, it uses DC power to support LEDs and other

components in the board. The technical details about our PSU is shown in Table

Operating Voltage | DC 9V-36V
Output Voltage | 5.2V/5A/25W
Output Ability | 9~24V input: 5.2V/6A/30W output
24~32V input: 5.2V/5A/25W output 32~36V input: 5.2V/3.5A/18W output Table 3.2 Technical Parameters of Controller’s PSU

Chapter 4 Development of Software

## Chapter 4 Development of Software

In this chapter, we will discuss the implementation of our code. To give a better

understanding about how the controller work from software aspect. The code structure

is shown in Figure 4-1.

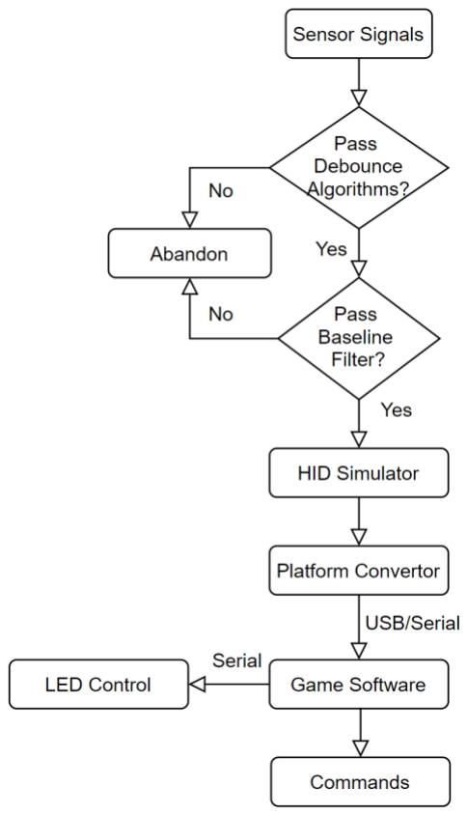
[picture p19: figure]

Figure 4.1 Data Flow Diagram

## 4.1 Debounce Algorithm and Baseline System

In this section, we will illustrate the implementation of debounce algorithm and

MPR121 Baseline system.

4.1.1 Debounce Algorithm

Contact bounce (also called chatter) is a common problem with mechanical

switches and relays, which arises as the result of electrical contact resistance (ECR)

phenomena at interfaces. Switch and relay contacts are usually made of springy metals.

Chapter 4 Development of Software

When the contacts strike together, their momentum and elasticity act together to cause

them to bounce apart one or more times before making steady contact. The result is a

rapidly pulsed electric current instead of a clean transition from zero to full current. The

effect is usually unimportant in power circuits, but causes problems in some analogue

and logic circuits that respond fast enough to misinterpret the on‑off pulses as a data

stream.[17] In the design of micro-contacts controlling surface structure (surface

roughness) and minimizing the formation of passivated layers on metallic surfaces are

instrumental in inhibiting chatter.

The effects of contact bounce can be eliminated by use of mercury-wetted

contacts, but these are now infrequently used because of the hazards of mercury.

Alternatively, contact circuit voltages can be low-pass filtered to reduce or eliminate

multiple pulses from appearing. In digital systems, multiple samples of the contact state

can be taken at a low rate and examined for a steady sequence, so that contacts can

settle before the contact level is considered reliable and acted upon. Bounce in SPDT

switch contacts signals can be filtered out using a SR flip-flop (latch) or Schmitt trigger.

All of these methods are referred to as 'debouncing'. [18]

The bounce problem will also happen in analog signal sensors like capacitive

sensors, shock sensors which are using in our sensors set. Because of lacking in test

circuit design and development budget, we choose software to do debounce. The

implementation of original debounce algorithm in MPR121 chip is obtaining multiple

samples and testing them with the baseline value. If any of these samples fail to pass the

test, these signals will be abandoned. However, this algorithm can cause serious input

latency. Hence, we implemented a debounce algorithm with rate-limiting and throttling

the frequency of sensor signals’ receiving. The effect of algorithm is shown in Figure 4-

2.

Chapter 4 Development of Software

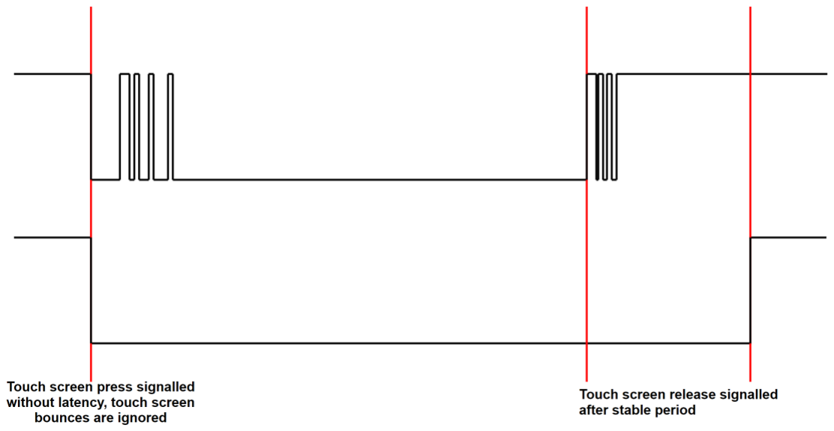
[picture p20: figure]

Figure 4.2 The Effect of Debounce Algorithm

From the figure we can find that the current level will be unstable when user press

and release the switch. Therefore, we limited the input frequency and set a fixed press duration. Currently, the world record for most mouse clicks in 1 second is 16CPS⁶
. [19]

Hence, we limited the input frequency to 20CPS. In other words, the controller will not

generate 2 signals in 50ms. The limitation even is a little bit higher than the record.

Therefore, it will not cause problems with missing input data for most users. By using

these measures, the bounces when user press and release the switch will be ignored.

Users can generate clear input signals and the game will have stable and correct actions.

4.1.2 Baseline System

Besides having bounce problem, touch sensors also have noise problem. In signal

processing, noise is a general term for unwanted (and, in general, unknown)

modifications that a signal may suffer during capture, storage, transmission, processing,

or conversion. [20] Hence, we also need an algorithm to filter them. The purpose of the

baseline filter is to “filter out touches” resulting in a system that is similar to a long-

term average but also takes into account that one specific signature. A touch must have

different properties than noise and environmental change with respect to the filter

response. This is accomplished through four register types that operate under different

6 CPS: Click per second

Chapter 4 Development of Software

conditions. These are Max Half Delta (MHD), Noise Half Delta (NHD), Noise Count

Limit (NCL) and Filter Delay Limit (FDL). [21] We can change the value of these

registers to customize the baseline filter and get clear touch signals. The data flow is

shown in Figure 4-3.

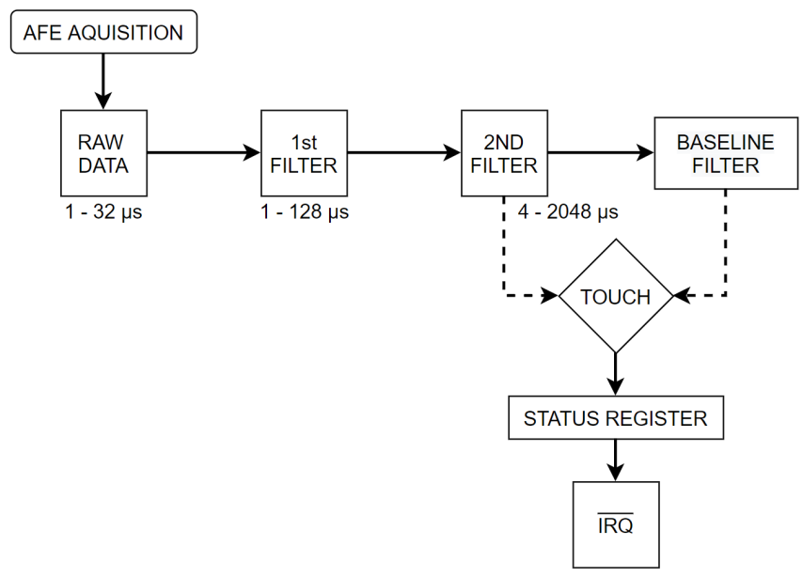
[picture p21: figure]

Figure 4.3 Data Flow in the MPR121

## 4.2 HID Device Simulation

4.2.1 Purpose of HID Device Simulation

In order to output signals which can be accepted by the game software, we need

to convert our controller into specific devices with correct driver which can be

identified by the target platform. For example, Windows 10 identify devices by their

HID drivers. We can use keyboard with keyboard drivers to input commands, but we

cannot use it with mouse drivers. Because the actions of some switches are not defined

in the driver. Hence, the system may cannot identify it or cannot receive right input

commands.

4.2.2 Selection of HID Device

There are various HID devices like gamepad, mouse, midi keyboard and other

devices in the world. To provide an unlimited software environment for the controller,

we consider the most suitable HID device is NKRO keyboard. NKRO keyboard has a

Chapter 4 Development of Software

significant feature that normal keyboards do not have. It has n-key rollover feature. This

means that each key is scanned completely independently by the keyboard hardware, so

that each keypress is correctly detected regardless of how many other keys are being

pressed or held down at the time. The drivers for PC system are also different. With

NKRO keyboard driver, the number of input commands which system can accept at the

same time is unlimited. Normal keyboards only have 6-key rollover which means they

can only input at most 6 keys once. It is not a big problem for daily used keyboard.

However, if the device is a game device, there is no doubt that it will greatly influence

the game experience especially for fighting game and rhythm game which are the most

popular genres in arcade games. Our controller has 32 touch sensors and 6 active IR

sensors. Hence, user can input at most 38 commands once which is much greater than

normal keyboard input limitation.

4.2.3 Implementation of HID Device Simulation

Arduino company has implemented a simple keyboard library [22]. However, it is

a normal keyboard library which means it can only input 6 keys once. Therefore, we

need to find another way to complete this function. Then, we find a third-party library

from GitHub. Its name is Arduino HID Project [23] which provide a simply approach

for developers to implement a NKRO keyboard.

The HID library provides two approaches to implement NKRO Keyboard

simulation. The first approach is similar with Arduino official keyboard library. We

need to use press() and release() functions to output a key command. The second

approach use add() and send() functions to output a series of added key commands. In

order to give clear game commands and improve users’ game experience, we use press

and release() to complete the basic logic of sending keyboard commands.

## 4.3 Platform Convertor

Most of arcade games can be played in PC platform by using various simulators

and similar fan-fiction works. These games can be played directly by the controller’s

default settings. However, there are a couple of arcade games having official console

games in PS4, XBOX and Nintendo Switch. In order to expand controller’s function

Chapter 4 Development of Software

and reduce the cost for new players to enjoy arcade games, we implemented a platform

convertor to make the controller still functional in console platforms.

Generally, we use third-party project GIMX [6] to implement our platform

convertor. GIMX is a free software that allows to use a computer as a hub for gaming

devices. It works on Windows and GNU/Linux platforms. It is compatible with

PlayStation and Xbox gaming consoles. The structure of GIMX is shown in Figure 4-4.

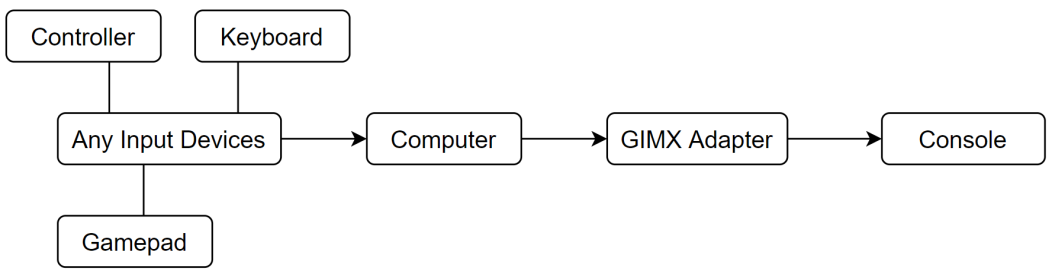
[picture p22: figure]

Figure 4.4 GIMX Structure

GIMX adapter is a USB adapter which can be made by AVR development board

like Sparkfun pro micro which is used in our main board. At present, GIMX project can

support PS4, PS3, Xbox One and Xbox 360. The controller will be converted to specific

console controller with good performance.

For Nintendo Switch, we use HID simulation function. The reason why we do

not use it to complete other platforms conversion is PlayStation and Xbox having an

extra identification process to check whether the connected device is the controller with

identification chip inside. However, for Nintendo Switch, it does not have such

procedure. Hence, we can simply change the HID information and simulate our

controller to be a Nintendo Switch official controller.

Unfortunately, because of the implementation approach of our controller, PC

mode cannot coexist with NS mode. In other words, we need to recompile the code to

change the mode of the controller to support different platform. It can be improved by

adding extra switch. For PlayStation and Xbox, they can coexist with PC mode.

Because GIMX is working in PC environment.

Chapter 4 Development of Software

## 4.4 Serial Communication and LED Control

Serial communication is the process of sending data one bit at a time,

sequentially, over a communication channel or computer bus. For most arcade

machines, they use serial communication to finish most of their data transmissions.

Hence, we implemented our LED control code by receiving values from the game

software. Sensors signals also can be transmitted by serial communication, but because

of the mechanism of serial communication, it has serious problem with data missing.

Sensor signals are the most significant part in our project. It should be stable with low

latency. Hence, if we want to use that we need to finish an extra structure for solving

this problem, it will spend much more time with little improvement for our controller.

Therefore, we decide to use USB communication for sensor signals and use Serial

communication for LED control.

There are totally 96 LEDs in our controller. They can be divided into 32 groups.

16 groups with 64 LEDs are touch area LEDs. 15 groups with 30 LEDs are the area

between two touch area. Finally, 1 group with 2 LEDs are redundant. By leaving an

extra redundant group can reduce the difficulty of production. We have left a

customizable value for users to change the data serial port. The controller will change

LEDs’ RGB value by receiving the data from that serial port.

Chapter 5 Testing

## Chapter 5 Testing

## 5.1 Main Board

In this section we will test the function of our main board. Generally, main board

has two functions. They are receiving signals and transmit these signals to game

platform. We tested the connection between four MPR121 chips and pro micro.

MPR121 chip has a begin() function to check the connection status. The result is shown

in Figure 5-1.

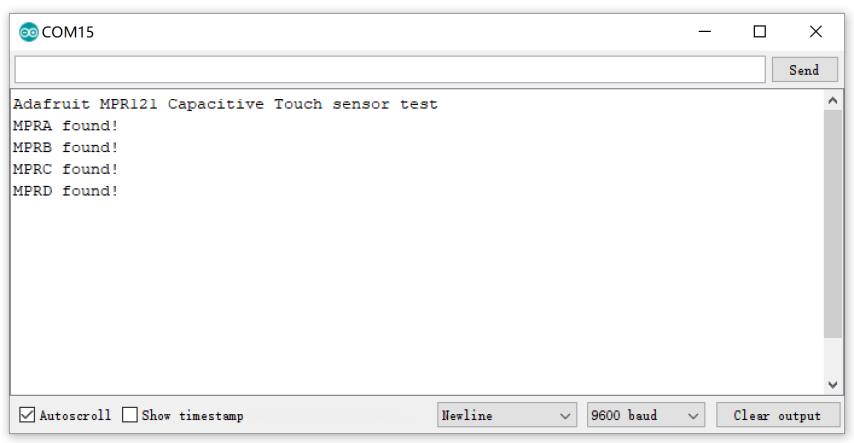
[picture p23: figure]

Figure 5.1 MPR121 Testing Result

Besides, power supply unit is functional, it can support all of our devices. The

finished main board is shown in Figure 5-2.

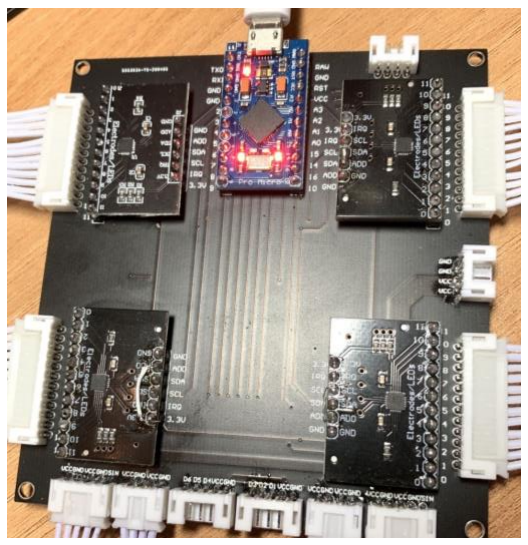
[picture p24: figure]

Figure 5.2 Complete Main Board

Chapter 5 Testing

## 5.2 Sensors Set

In this section, we test the function of all the sensors in our sensors set. There are

totally 8 actions divided by action types, speed and intensity. The result is shown in

Table 5-1. According to the result, we can find that the touch screen can receive heavy

click, hold, fast slide well and active IR sensors can always track users’ action clearly.

However, because of the theory of self-capacitance sensors, light click and low speed

slide have serious signal missing problems when we touch the sensor with LGP.

Fortunately, the problem can be simply fixed by removing LGP.

Actions Result | Click (Light) | Click (Heavy) | Hold | Slide (Fast) | Slide (Normal) | Slide (Slow) | Air (Flick) | Air (Hover)
Received | 21 | 48 | 49 | 41 | 32 | 17 | 50 | 47
Missed | 29 | 2 | 1 | 12 | 18 | 33 | 0 | 3
Input Number | 50 | 50 | 50 | 50 | 50 | 50 | 50 | 50

Table 5.1 The Result of Sensor Testing with LGP

Actions Result | Click (Light) | Click (Heavy) | Hold | Slide (Fast) | Slide (Normal) | Slide (Slow) | Air (Flick) | Air (Hover)
Received | 49 | 48 | 49 | 47 | 48 | 43 | 50 | 48
Missed | 1 | 2 | 1 | 3 | 2 | 7 | 0 | 2
Input Number | 50 | 50 | 50 | 50 | 50 | 50 | 50 | 50

Table 5.2 The Result of Sensor Testing without LGP

Chapter 6 Conclusion

## Chapter 6 Conclusion

## 6.1 Conclusion

We have presented an approach to build a customizable universal arcade

controller. The controller can support most of arcade games in the market and some of

the console games which have similar input mechanism like arcade games. All the

components in the controller are budget and easy for user to maintenance. We designed

sensors set and main board two individual structures which can let users play

completely different games by using the same controller. Besides, they are protected

well by the shell structure. Hence, the controller can work properly in poor environment

without regular maintenance. Therefore, it will be a good device for new players who

want to play arcade games.

## 6.2 Future work

We use self-capacitance structure to make our touch screen, but its sensitivity is a

little bit too low to track every small action made by users. Using mutual- capacitance

structure may have better performance. Besides, a functional hardware debounce

structure should be added to the PCB. The debounce algorithm cannot handle all the

situation. Some noises still will cause unexpected input signals.

The PCB design of touch sensors should add extra JST connectors to further

reduce the difficulty of production and maintenance. The main board should a little bit

larger to give more space for power and ground traces.

Reference & Bibliography

## Reference & Bibliography

[1] Wikipedia, “Arcade game”, https://en.wikipedia.org/wiki/Arcade_game
[2] Wikipedia, “Chunithm”, https://en.wikipedia.org/wiki/Chunithm
[3] H. Lee, H. Jeong and J. Han, "Arcade video game platform built upon multiple

sensors," 2008 IEEE International Conference on Multisensor Fusion and

Integration for Intelligent Systems, Seoul, 2008, pp. 111-113.

[4] Sambe, Yukiharu (2009). "Japan's Arcade Games and Their Technology". Lecture

Notes in Computer Science. Entertainment Computing– ICEC 2009.

[5] Bemanicn, “Chinese rhythm games map”, https://map.bemanicn.com/.
[6] GIMX, “GIMX – GIMX adapts your gaming devices!”, https://blog.gimx.fr/
[7] E. S. Koptev and D. V. Ryabchinskiy, "Decrease of the Error of Measurement of

Self-Capacitance with Least Squares Method," 2018 XIV International Scientific-

Technical Conference on Actual Problems of Electronics Instrument Engineering

(APEIE), Novosibirsk, 2018, pp. 252-254.

[8] Sensor Technology, “Infrared sensors”,

https://wiki.metropolia.fi/display/sensor/Infrared+sensors

[9] Worldsemi, “WS2812B”, https://cdn-shop.adafruit.com/datasheets/WS2812B.pdf
[10] Microsoft word, “TM1812_V1.4”, https://www.led-

stuebchen.de/download/TM1812_V1.4_EN.pdf

[11] Diytrade, “Laser Light Guide Plate”,

https://backlightunit.diytrade.com/sdp/1442761/4/cp-

6446181/0/Laser_Light_Guide_Plate.html

[12] Adafuit, “Adafruit MPR121 12-Key Capacitive Touch Sensor Breakout Tutorial”,

https://learn.adafruit.com/adafruit-mpr121-12-key-capacitive-touch-sensor-

breakout-tutorial/overview

[13] Arduino, “Arduino-Home”, https://www.arduino.cc/
[14] "How many Arduinos are "in the wild?" About 300,000". Adafruit Industries. May

15, 2011. Retrieved 2013-05-26, https://blog.adafruit.com/2011/05/15/how-many-

arduinos-are-in-the-wild-about-300000/.

[15] "Arduino FAQ – With David Cuartielles". Malmö University. April 5, 2013.

Retrieved 2014-03-24, http://medea.mah.se/2013/04/arduino-faq/.

Reference & Bibliography

[16] Wikipedia, “JST connector”, https://en.wikipedia.org/wiki/JST_connector
[17] Walker, PMB, Chambers Science and Technology Dictionary, Edinburgh, 1988,

ISBN 1-85296-150-3

[18] Wikipedia, “Switch”, https://en.wikipedia.org/wiki/Switch
[19] Click Speed Test, “Click per second”, https://clickspeedtest.com/clicks-per-

second.html#record

[20] Vyacheslav Tuzlukov (2010), Signal Processing Noise, Electrical Engineering and

Applied Signal Processing Series, CRC Press. 688 pages. ISBN 9781420041118

[21] Freescale, “MPR121 Baseline System”, https://www.nxp.com/docs/en/application-

note/AN3891.pdf

[22] Arduino, “Keyboard”,

https://www.arduino.cc/reference/en/language/functions/usb/keyboard/

[23] Github, “HID”, https://github.com/NicoHood/HID
[24] B. Wu, X. Zhang, X. Liu and C. He, "An Analytical Model for Predicting the Self-

Capacitance of Multi-Layer Circular-Section Induction Coils," in IEEE

Transactions on Magnetics, vol. 54, no. 5, pp. 1-7, May 2018, Art no. 6201007.

[25] H. Kim, Y. Kwak, K. Cho, S. Lee and G. Ahn, "An analog front-end for self-

capacitance touch sensing with environmental noise reduction technique," 2018

International Conference on Electronics, Information, and Communication

(ICEIC), Honolulu, HI, 2018, pp. 1-3.

Resume

## Resume

## 1. Resume

Name: Chen Han Dong

Gender: Male

Email: chd19972011@163.com

Education:

2013/9 ~ 2016/6, High School, ZHENSHI High School.

2016/9 ~ 2020/6, Bachelor of Science, Macau University of Science and

Technology.

Awards:

10/2019 The 5rd China “Internet +” College Students Innovation and Entrepreneurship

Competition - National Silver Award.

10/2019 "Challenge Cup" Extracurricular Academic Science and Technology Works

Competition in National College Students – National Second Prize

08/2019 Asian Robot Education and Innovation Conference - Bronze Award in

University Group

05/2018 Macao University of Science and Technology - Outstanding Academic Third

Prize in 2018-2019 Academic Year

11/2017 Macau Youth Innovation and Entrepreneurship Competition “Shenzhen Hong

Kong and Macau Youth Innovation and Entrepreneurship Competition Macau” –

Second Prize in Internet Plus Group

11/2017 The 3rd China “Internet +” College Students Innovation and Entrepreneurship

Competition - National Bronze Award

Acknowledgement

## Acknowledgement

We are particularly grateful to Dr. Dai and other people who helped us to make

our controller come true. This project is inspired by multiple open source controller

projects. Thanks for their works. They did a lot for the arcade and hardware

development community.

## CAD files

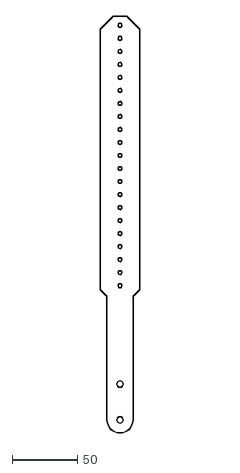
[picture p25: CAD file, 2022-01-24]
CAD Blueprints/Air Components/Sensor Support.dxf
30.0 x 320.0

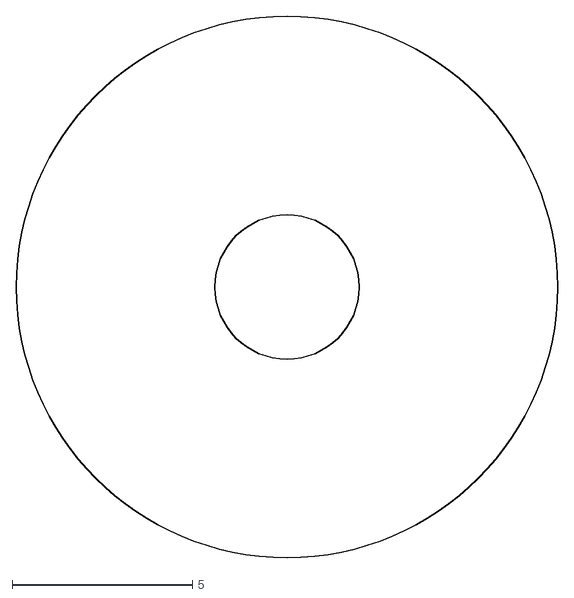
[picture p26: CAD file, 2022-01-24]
CAD Blueprints/Other Components/M4 Support.dxf
15.0 x 15.0

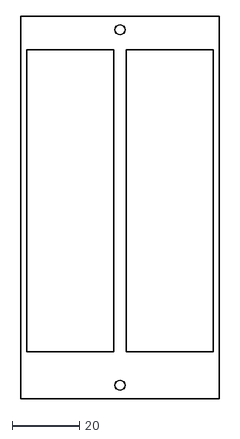
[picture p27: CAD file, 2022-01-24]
CAD Blueprints/PCB/pcb.dxf
59.2 x 114.0

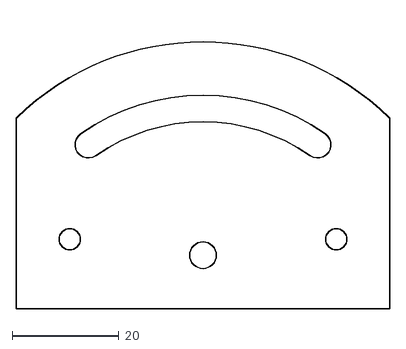
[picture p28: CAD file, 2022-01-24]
CAD Blueprints/Air Components/Angle Fixer.dxf
70.0 x 54.8

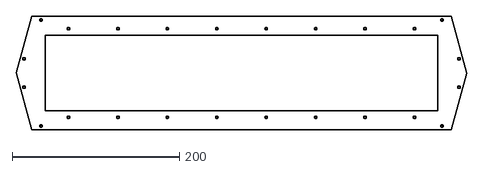
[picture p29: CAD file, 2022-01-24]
CAD Blueprints/Box/Surface.dxf
539.1 x 136.0

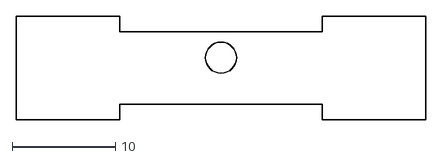
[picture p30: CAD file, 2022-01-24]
CAD Blueprints/Other Components/LED Support.dxf
39.6 x 10.0

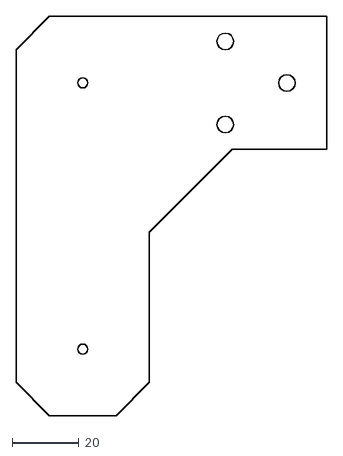
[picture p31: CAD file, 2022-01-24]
CAD Blueprints/Air Components/Base.dxf
93.4 x 120.0

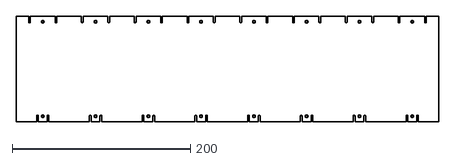
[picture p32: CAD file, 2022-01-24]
CAD Blueprints/Box/Acrylic Diffuser.dxf
473.6 x 118.0

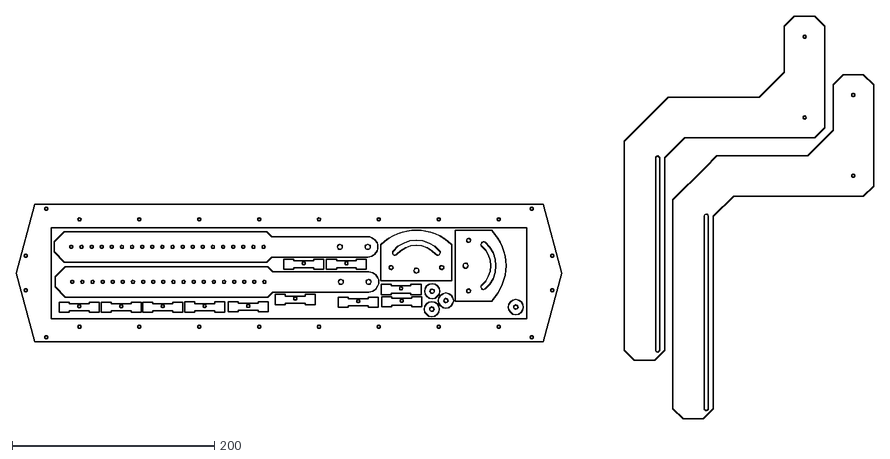
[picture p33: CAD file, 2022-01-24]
CAD Blueprints/CNC Blueprints/Air Set.dxf
847.5 x 397.7

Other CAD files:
CAD Blueprints/Main.dwg
CAD Blueprints/Box/Box.dwg
CAD Blueprints/CNC Blueprints/Air Base CNC ALL.dwg
CAD Blueprints/CNC Blueprints/Acrylic Diffuser.dwg
CAD Blueprints/PCB/chunithm-16key.DWG
CAD Blueprints/CNC Blueprints/Air Base CNC.dwg
CAD Blueprints/Box/Box_2.4Hole_SideHole_07.dwg
CAD Blueprints/CNC Blueprints/Air Acrylic CNC.dwg
CAD Blueprints/Air Components/Angle Fixer.dwg
CAD Blueprints/Air Components/Base.dwg
CAD Blueprints/Air Components/Sensor Support.dwg
CAD Blueprints/Box/Acrylic Diffuser.dwg
CAD Blueprints/Box/Surface.dwg
CAD Blueprints/Other Components/LED Support.dwg
CAD Blueprints/Other Components/M4 Support.dwg

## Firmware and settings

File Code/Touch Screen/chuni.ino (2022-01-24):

/***************************
  适用于mpr121触摸按键的代码
  代码已经经过测试可以使用
  如果遇到air开关是通光高电平，遮光低电平，仅需把HIGH改成LOW即可
  加了RGB
  更换了键盘库
  需要修改的地方是uint16_t KeyBoard[50]这一项中对应的按键与air的按键
  还有Adafruit_MPR121.h文件中的触摸阈值与release阈值
  不同的海拔，湿度，温度环境下，不同面积的金属箔和金属箔隔着触碰使用的阈值都不一样
  请逐一调低/高数值进行测试
  我使用的触摸阈值是3，release阈值是1
  Adafruit编写库时使用的触摸阈值是12，release是6yn
  库非本人编写，我只是对库的注释进行了翻译，请支持正版，购买adafruit销售的mpr121
  特殊按键注释
  NKROKeyboard
  KEY_LEFT_BRACE,         // [  0xDB
  KEY_RIGHT_BRACE,        // ]  0xDD
  KEY_PERIOD,            // .   0xBE
  KEY_SLASH,            // /    0xBF
  KEY_COMMA,            // ,    0xBC
  KEY_QUOTE,            // '    0xDE
 KEY_SEMICOLON,          // ;   0xBA
**************************/
#include <Wire.h> //I2C库
#include <FastLED.h>//led库
#define NUM_LEDS 16//灯数量
#define led_PIN 10//灯的脚针
CRGB leds[NUM_LEDS];
#include "HID-Project.h" //keyboard库
#include "Adafruit_MPR121.h" //MPR121库
#define MPRA 0x5A
#define MPRB 0x5B     //MPR121模块ADD脚默认地址/接地为 0x5A, 连接到 3.3V 为 0x5B       
#define MPRC 0x5C     // 连接到 SDA 为 0x5C ， 连接 SCL 为 0x5D
#define MPRD 0x5D

#define amount 4 //mpr121数量
const int air_key1 = 4;//定义air按键1,2,3,4,5,6
const int air_key2 = 5;
const int air_key3 = 6;
const int air_key4 = 7;
const int air_key5 = 8;
const int air_key6 = 9;
int airState = 0;

static int serial_count;
static int serial_delay, serial_prevdelay;
static unsigned long serial_timer;

Adafruit_MPR121 capA = Adafruit_MPR121();  //创建对象
Adafruit_MPR121 capB = Adafruit_MPR121();
Adafruit_MPR121 capC = Adafruit_MPR121();
Adafruit_MPR121 capD = Adafruit_MPR121();


uint16_t lasttouchedA = 0; //创建相应的状态变量  lasttouchedA是上次的状态，currtouchedA是当前状态，两者用于检测引脚状态是否又变动。B，C，D与此相同。
uint16_t currtouchedA = 0;
uint16_t lasttouchedB = 0;
uint16_t currtouchedB = 0;
uint16_t lasttouchedC = 0;
uint16_t currtouchedC = 0;
uint16_t lasttouchedD = 0;
uint16_t currtouchedD = 0;

uint16_t Touched[50];  //变更为按下引脚的记录数组

uint16_t Released[50]; //变更为松开引脚的记录数组
/*
uint16_t KeyBoard[50] = {'&', 'i', '8', 'u', '7', 'y', '6', 't', '5', 'r', '4', 'e', '3', 'w', '2', 'q', '1'};//第一个是无效的按键，不必修改，从第二个开始
uint16_t KeyBoarddown[50] = {'&', ',', 'k', 'm', 'j', 'n', 'h', 'b', 'g', 'v', 'f', 'c', 'd', 'x', 's', 'z', 'a'};
*/
uint16_t KeyBoard[50] = {'&', '1', 'q', '2', 'w', '3', 'e', '4', 'r', '5', 't', '6', 'y', '7', 'u', '8', 'i'};//第一个是无效的按键，不必修改，从第二个开始
uint16_t KeyBoarddown[50] = {'&', 'a', 'z', 's', 'x', 'd', 'c', 'f', 'v', 'g', 'b', 'h', 'n', 'j', 'm', 'k', ','};
//把脚针改为键盘按键,目前对应的是从按键的左边开始到右边分别为A0脚针到B3脚针

void led_com_tasklet() {
  
  if (Serial.available() >= 3) {
    leds[15 - serial_count].r = Serial.read();
    leds[15 - serial_count].g = Serial.read();
    leds[15 - serial_count].b = Serial.read();
    
    serial_count++;
    if (serial_count == 16) {
      FastLED.show();
      while(Serial.read() != -1);
      serial_delay = serial_prevdelay;
      Serial.write("A"); // ACK
      serial_count = 0;
    }
  }
  if (--serial_delay == 0) {
    while(Serial.read() != -1);
    Serial.write('A');
    int interval = millis() - serial_timer;
    if (interval > 500) {
      serial_prevdelay = serial_prevdelay * 0.9;
    } else {
      serial_prevdelay = serial_prevdelay * 1.1;
    }
    serial_delay = serial_prevdelay;
    serial_timer += interval;
  }
}

void gsled_commit() {
  FastLED.show();
}

void gsled_init() {
  for (int i = 0; i < NUM_LEDS; i++) {
    leds[i] = 0x000000;
  }
  FastLED.addLeds<NEOPIXEL, led_PIN>(leds, NUM_LEDS);
  Serial.begin(9600);
  Serial.setTimeout(0);
  serial_prevdelay = serial_delay = 1000;
  serial_timer = millis();
  serial_count = 0;
}


void setup() {
  gsled_init();
  
  MPR121Check();//检测I2C上的设备是否在线，切勿删掉此函数，否则Pro micro无法正常工作
  NKROKeyboard.begin(); //NKROKeyboard库初始化
  NKROKeyboard.releaseAll(); //所有键盘按键松开
  /*
  pinMode(air_key4, INPUT_PULLUP);//air按键脚针4,5,6,7,8,9
  pinMode(air_key1, INPUT_PULLUP);
  pinMode(air_key2, INPUT_PULLUP);
  pinMode(air_key3, INPUT_PULLUP);
  pinMode(air_key5, INPUT_PULLUP);
  pinMode(air_key6, INPUT_PULLUP);
  */
  //FastLED.addLeds<WS2812B, led_PIN>(leds, NUM_LEDS);//设置RGB灯
  
}

void MPR121Check() //MPR121初始化函数，检测是否在线
{
  if (amount >= 1)
  {
    if (!capA.begin(MPRA))
    {
      Serial.println("MPRA not found, check wiring?");
      delay(1);
    }
    else
    {
      Serial.println("MPRA found!");
    }
  }
  if (amount >= 2)
  {
    if (!capB.begin(MPRB))
    {
      Serial.println("MPRB not found, check wiring?");
      delay(1);
    }
    else
    {
      Serial.println("MPRB found!");
    }
  }
  if (amount >= 3)
  {
    if (!capC.begin(MPRC))
    {
      Serial.println("MPRC not found, check wiring?");
      delay(1);
    }
    else
    {
      Serial.println("MPRC found!");
    }
  }
  if (amount >= 4)
  {
    if (!capD.begin(MPRD))
    {
      Serial.println("MPRD not found, check wiring?");
      delay(1);
    }
    else
    {
      Serial.println("MPRD found!");
    }
  }
}


void TandRcheck()  //检测MPR121上的引脚变动情况，采用混合扫描
{
  uint8_t n = 0;
  uint8_t n2 = 0;
  uint8_t i = 0;
  if (amount >= 1)//地址为0x5A的mpr121
  {
    currtouchedA = capA.touched();
    for ( i = 0; i < 8; i++) {

      if ((currtouchedA & _BV(i)) && !(lasttouchedA & _BV(i)) ) {
        if(i < 4)
        {
          Touched[n] = i + 1;
          NKROKeyboard.press(KeyBoarddown[Touched[n]]);
        }
        else
        {
          Touched[n] = i + 1 - 4;
          NKROKeyboard.press(KeyBoard[Touched[n]]);
        }
        //leds[i] = CRGB(0, 255, 255);//(红色的亮度，绿，蓝）//数值请从0-255中选择
        FastLED.show();
        n++;
      }

      if (!(currtouchedA & _BV(i)) && (lasttouchedA & _BV(i)) ) {
        
        
         if(i < 4)
         {
          Released[n2] = i + 1;
          NKROKeyboard.release(KeyBoarddown[Released[n2]]);
         }
        else
        {
          Released[n2] = i + 1 - 4;
          NKROKeyboard.release(KeyBoard[Released[n2]]);
        }
        //leds[i] = CRGB(130, 255, 0);
        FastLED.show();
        n2++;
      }
    }

    lasttouchedA = currtouchedA;
  }

  if (amount >= 2)//地址为0x5B的mpr121
  {
    currtouchedB = capB.touched();
    for ( i = 0; i < 8; i++) {

      if ((currtouchedB & _BV(i)) && !(lasttouchedB & _BV(i)) ) {
        
        if(i < 4)
        {
          Touched[n] = i + 4 + 1;
          NKROKeyboard.press(KeyBoarddown[Touched[n]]);
        }
        else
        {
          Touched[n] = i + 4 + 1 - 4;
          NKROKeyboard.press(KeyBoard[Touched[n]]);
        }
        //leds[i + 12] = CRGB(0, 255, 255);
        FastLED.show();
        n++;
      }
      if (!(currtouchedB & _BV(i)) && (lasttouchedB & _BV(i)) ) {
        
        if(i < 4)
        {
          Released[n2] = i + 4 + 1;
          NKROKeyboard.release(KeyBoarddown[Released[n2]]);
        }
        else
        {
          Released[n2] = i + 1 + 4 - 4;
          NKROKeyboard.release(KeyBoard[Released[n2]]);
        }
        //leds[i + 12] = CRGB(130, 255, 0);
        FastLED.show();
        n2++;
      }
    }

    lasttouchedB = currtouchedB;
  }

  if (amount >= 3)//地址为0x5C的mpr121
  {
    currtouchedC = capC.touched();
    for ( i = 0; i < 8; i++) {

      if ((currtouchedC & _BV(i)) && !(lasttouchedC & _BV(i)) ) {
        
        if(i < 4)
        {
          Touched[n] = i + 4 + 4 + 1;
          NKROKeyboard.press(KeyBoarddown[Touched[n]]);
        }
        else
        {
          Touched[n] = i + 1 + 4 + 4 - 4;
          NKROKeyboard.press(KeyBoard[Touched[n]]);
        }
        FastLED.show();
        n++;
      }
      if (!(currtouchedC & _BV(i)) && (lasttouchedC & _BV(i)) ) {
       
        if(i < 4)
        {
          Released[n2] = i + 4 + 4 + 1;
          NKROKeyboard.release(KeyBoarddown[Released[n2]]);
        }
        else
        {
          Released[n2] = i + 1 + 4 + 4 - 4;
          NKROKeyboard.release(KeyBoard[Released[n2]]);
        }
        FastLED.show();
        n2++;
      }
    }

    lasttouchedC = currtouchedC;
  }

  if (amount >= 4)//地址为0x5D的mpr121
  {
    currtouchedD = capD.touched();
    for ( i = 0; i < 8; i++) {

      if ((currtouchedD & _BV(i)) && !(lasttouchedD & _BV(i)) ) {
        
        if(i < 4)
        {
          Touched[n] = i + 4 + 4 + 4 + 1;
          NKROKeyboard.press(KeyBoarddown[Touched[n]]);
        }
        else
        {
          Touched[n] = i + 4 + 4 + 4 + 1 - 4;
          NKROKeyboard.press(KeyBoard[Touched[n]]);
        }
        FastLED.show();
        n++;
      }
      if (!(currtouchedD & _BV(i)) && (lasttouchedD & _BV(i)) ) {
       
        if(i < 4)
        {
          Released[n2] = i + 4 + 4 + 4 + 1;
          NKROKeyboard.release(KeyBoarddown[Released[n2]]);
        }
        else
        {
          Released[n2] = i + 4 + 4 + 4 + 1 - 4;
          NKROKeyboard.release(KeyBoard[Released[n2]]);
        }
        FastLED.show();
        n2++;
      }
    }

    lasttouchedD = currtouchedD;
  }
}




void loop() {

  led_com_tasklet();
  gsled_commit();

  TandRcheck();

  //char LED_com = "0";
  
  /*
  if(Serial.available() > 0)
  {
    LED_com = Serial.read();
    Serial.print(LED_com);
  }*/
  
  airState = digitalRead(air_key1); //按键1
  if (airState == LOW)
    NKROKeyboard.press(KEY_SLASH);
  else 
    NKROKeyboard.release(KEY_SLASH);
 
  airState = digitalRead(air_key2);//按键2
  if (airState == HIGH)
    NKROKeyboard.press(KEY_PERIOD);
  else
    NKROKeyboard.release(KEY_PERIOD);
  
  airState = digitalRead(air_key3); //按键3
  if (airState == HIGH)
    NKROKeyboard.press(KEY_QUOTE);
  else
    NKROKeyboard.release(KEY_QUOTE);
    
  airState = digitalRead(air_key4);//按键4
  if (airState == LOW)
    NKROKeyboard.press(KEY_SEMICOLON);
  else
    NKROKeyboard.release(KEY_SEMICOLON);
    
  airState = digitalRead(air_key5); //按键5
  if (airState == HIGH)
    NKROKeyboard.press(KEY_RIGHT_BRACE);
  else
    NKROKeyboard.release(KEY_RIGHT_BRACE);

  airState = digitalRead(air_key6);//按键6
  if (airState == HIGH)
    NKROKeyboard.press(KEY_LEFT_BRACE);
  else
    NKROKeyboard.release(KEY_LEFT_BRACE);
    
  gsled_commit();
}

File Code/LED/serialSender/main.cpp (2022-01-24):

#include <iostream>
#include <string>
#include <stdlib.h>
#include <SerialPort.h>

using namespace std;
const char* port = "\\\\.\\COM3";
char output[MAX_DATA_LENGTH];
char imcoming[MAX_DATA_LENGTH];

int main()
{
	SerialPort LEDcontrol(port);

	if (LEDcontrol.isConnected())
		cout << "Connection Success" << endl;
	else
		cout << "Connection Fail" << endl;

	while (LEDcontrol.isConnected())
	{
		string command;
		cin >> command;
		char* charArray = new char[command.size() + 1];
		copy(command.begin(), command.end(), charArray);
		charArray[command.size()] = '\n';

		LEDcontrol.writeSerialPort(charArray, MAX_DATA_LENGTH);
		LEDcontrol.readSerialPort(output, MAX_DATA_LENGTH);

		cout << output;

		delete[] charArray;
	}
	return 0;
}
